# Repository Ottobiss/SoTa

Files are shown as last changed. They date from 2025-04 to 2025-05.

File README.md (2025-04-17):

<div align="center">
<p>
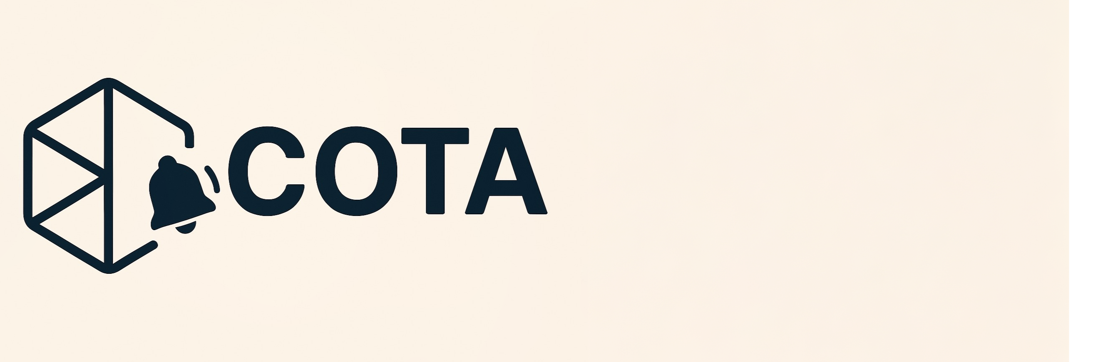
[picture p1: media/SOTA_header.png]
SOTA system banner

</p>




</div>

# 💊 Умная Таблетница «СОТА»

**Инженерно-программный проект**, направленный на создание универсальной системы контроля приёма различных лекарственных препаратов. Подразумевающий разработку умной таблетницы, сочетающей в себе простоту и эффективность использования. 

---
## 📷 Демонстрация

| Устройство | Интерфейс (...) |
|---|---|
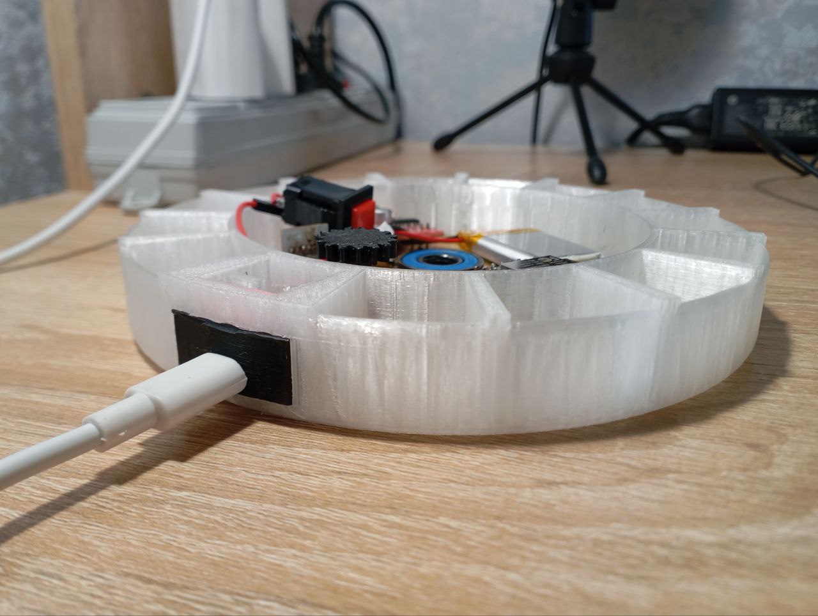
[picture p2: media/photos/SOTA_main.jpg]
SOTA demonstration
|  | ### |

---
## 📊 Что за «СОТА»?

Это **умная таблетница**, которая:
- 📱 Легко привязывается к специальному мобильному приложени.
- ✒️ Быстро и легко настраивается, учитывая при этом запросы пользователя.
- 🌐 Может подключаться к сети для более эффективной работы.
- 🔔 Напоминает о приёме лекарственных препаратов по расписанию.
- 💡 Подсвечивает и открывает нужный отсек в соответствии с конфигурацией.
- 📊 Хранит журнал приёмов и ведёт статистику.

---
## 🎯 Общие цели и принципы 
| Цель | Принцип |
|---|---|
| ⏰ Своевременный приём лекарств | Гибкая и удобная в настройке система, которая привязывает выдачу препарата к определённому времени. |
| 🔐 Исключение ошибок | Выдача препаратов производится автоматически без вмешательства человека. |
| 📲 Удалённый доступ | Возможность просмотра данных и настройки через приложение. |
| 🛠 Компактность конструкции | Умную таблетницу можно спокойно переносить в небольших сумках, рюкзаках и т.д. |
---
## 📦 Структура репозитория

```text
SoTa/
├── hardware/           ← Аппаратная часть: схемы, 3D-модели, прошивка
│   ├── schematics/     ─ Электросхемы, подключения
│   ├── 3d_models/      ─ Корпус таблетницы (STL/M3D/A3D)
│   └── firmware/       ─ Код для микроконтроллера (ESP32)

├── software/           ← Программная часть: веб-интерфейс, сервер, логика
│   ├── backend/        ─ Серверное API, алгоритмы на Python
│   └── app/    ─ автономное приложение

├── docs/               ← Документация, презентация, инструкции
├── media/              ← Фото, мокапы, скриншоты, демонстрации, лого и прочее
└── README.md           ← Вы здесь :)
```

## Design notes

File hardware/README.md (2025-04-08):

# 💡 Проектирование

Основной особенностью умной таблетницы **«СОТА»** является её небольшой размер, позволяющий носить её с собой в течение дня или держать рядом на небольшом столике. Именно поэтому при проектировании устройства особое внимание уделялось **балансу** между **вместимостью и компактностью**. 

---
## 🔧 Модель корпуса

Основной конструкционной идеей является механизм **револьверного типа**. Крашка таблетницы может поворачиваться на **заданную ячейку**, совершая выдачу **препаратов**, находящихся в этой ячейке.

| Ячейки | Крышка | Зарядный бокс |
|---|---|---|
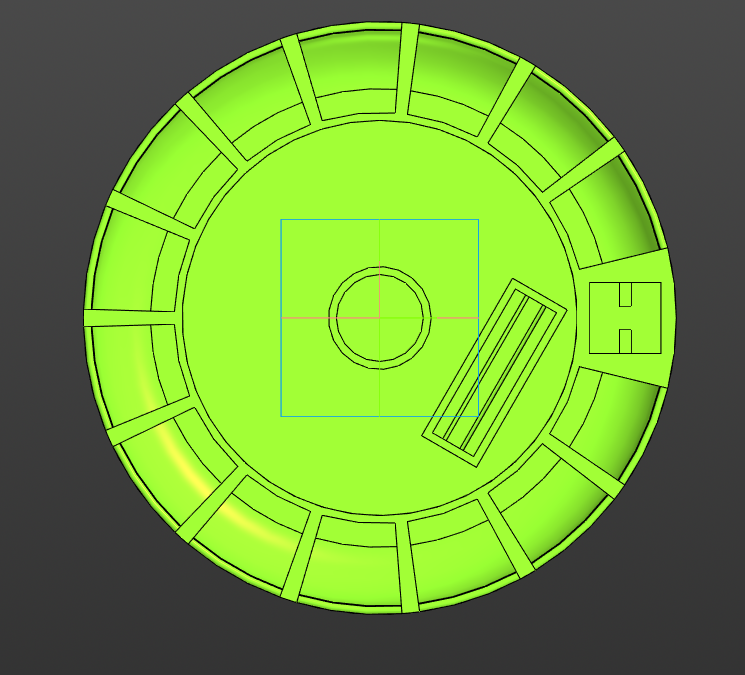
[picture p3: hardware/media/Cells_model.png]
Cells of SOTA
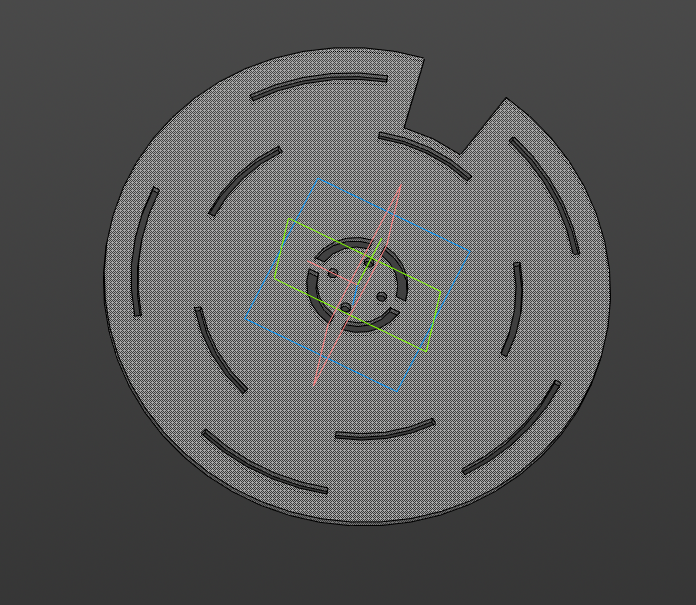
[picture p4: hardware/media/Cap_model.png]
Cap of SOTA
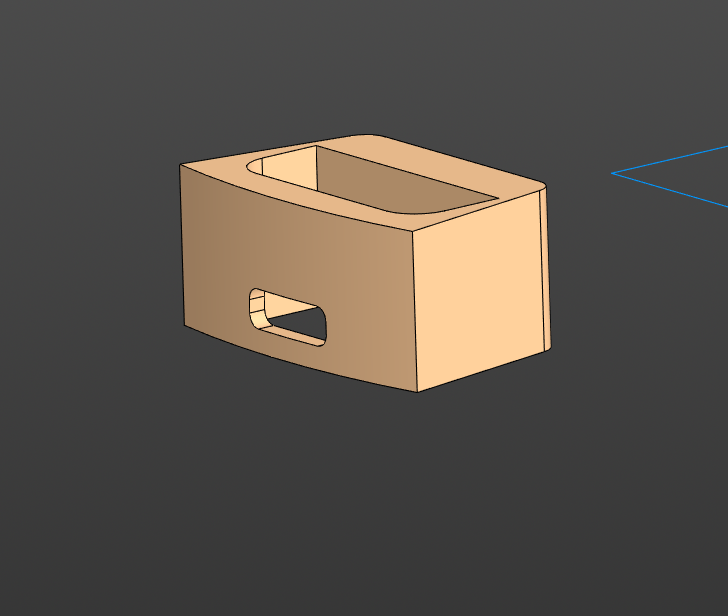
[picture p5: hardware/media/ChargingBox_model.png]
Charging box of SOTA
|  |  |  |
| Всего корпус таблетницы содержит **15 ячеек**, одна изкоторых является заглушкой. Размещение препаратов в ячейках может быть произвольным. | Крышка предназначена для выдачи препаратов в соответствии с **расписанием**, настроенным ранее в приложении, так, крышка проворачивается на нужную ячейку. | Зарядный бокс выполняет скорее **демонстративную функцию**. За ним находится зарядная плата с разъёмом **Type-C**, позволяющим программировать и заряжать умную таблетницу. |
---
## ⚡ Электроника

Решение делать **печатную плату** было принято не сразу. Сначала рассматривались варианты с производством платы по технологии **ЛУТ-а**, но она к сожалению не обладала достаточной точностью. Переносить дорожки с бумаги на **текстолит** было досточно проблематичным, даже при условии толщины дорожки в **1 мм**.
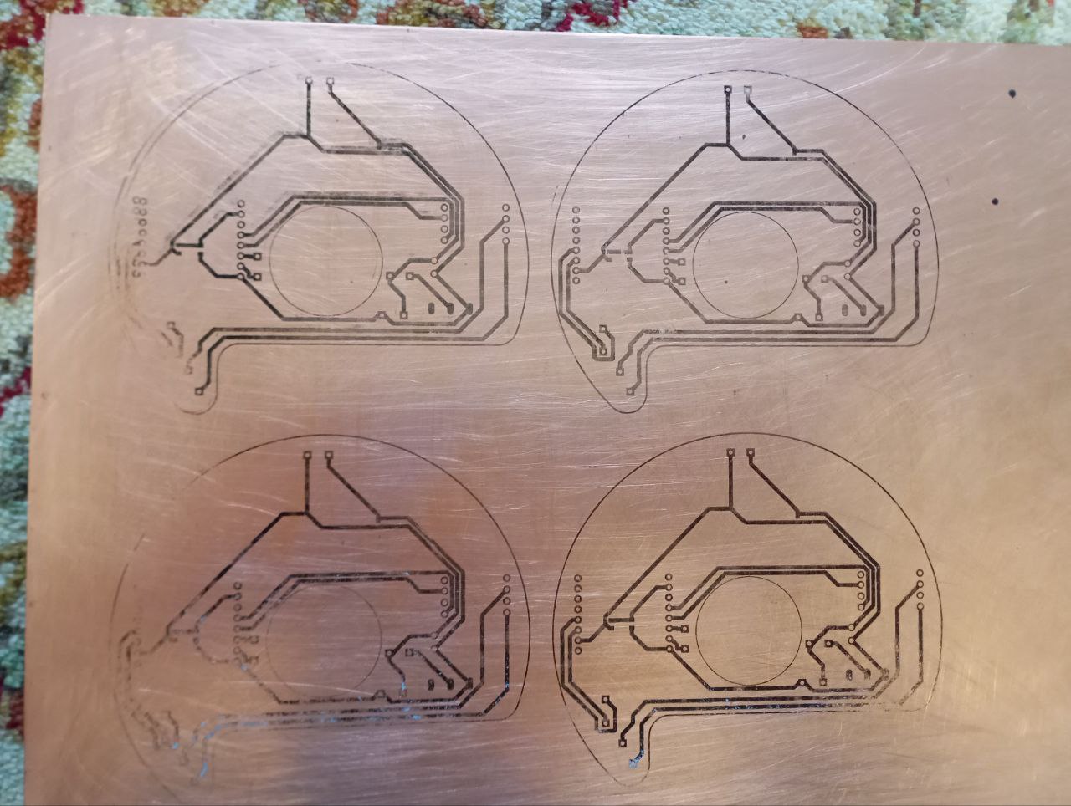
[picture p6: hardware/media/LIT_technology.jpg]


<p align="center"><i>Собственнл лист текстолита с несколькими платами. Да, из-за особенностей технологии некоторые дорожки перенеслись плохо и их пришлось дорисовывать.</i></p>

Была создана печатная плата. Она уже позволяла разместить больше компонет. Также ширина дорожек питания сократилась до **0.7 мм**, а ширина других до **0.3 мм**.

| Печатная плата 2D | Принципиальная схема |
|---|---|
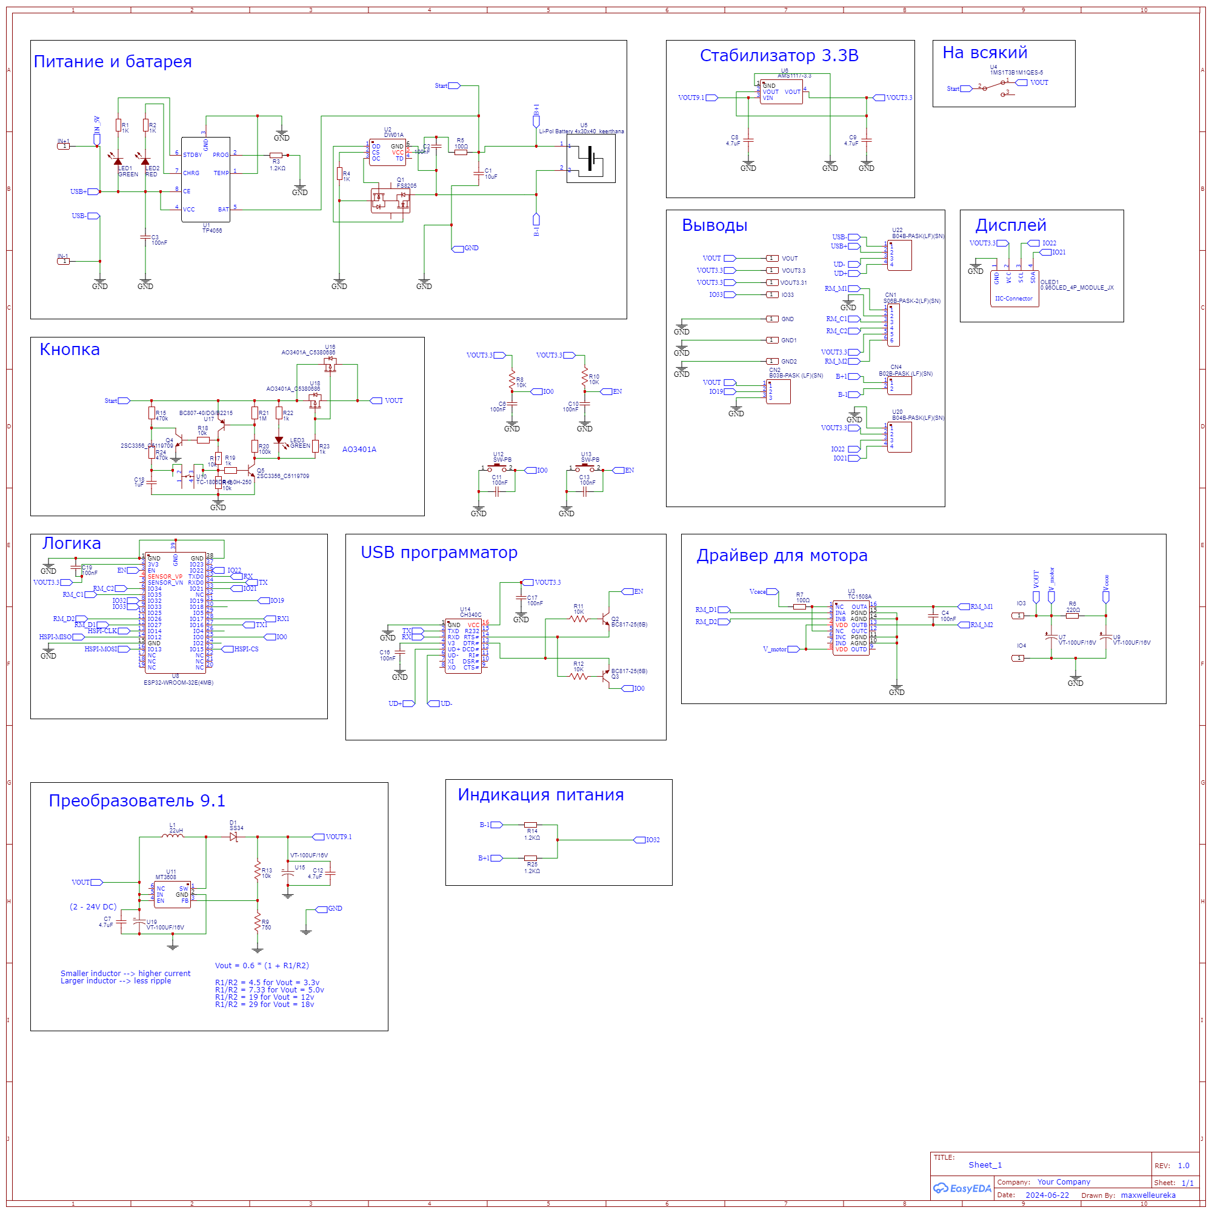
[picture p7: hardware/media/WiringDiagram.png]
Wiring diagram of SOTA
| <p align="center">Printing board of SOTA</p> |  |

## ▶️ Электроника в общем

```text
          +----------------------+
          |  Аккумулятор Li-Pol  |               #Питание поступает от аккумулятора 3.7 V и преобразуется в 9 V.
          +----------------------+               #Далее 9 V через стабилизатор понижаются до 3.3 V и проходят дальше.
                    |                            #От стабилизатора питаются ESP32, мотор с энкодером и LED-лента.
                  3.7 V                          #Управление всеми компонентами осуществляется с микроконтроллера.
                    ↓
          +----------------------+
          |  Преобразователь 9 V |
          +----------------------+
                    |                         
                   9 V                        +----------------------+
                    ↓                    ―― → |  LED лента           | ← ―
          +----------------------+      |     +----------------------+    |
          |                      |      |     +----------------------+    |
          |  Стабилизатор 3.3 V  | ―― 3.3 V → |  Мотор с энкодером   |    |
          |                      |            +----------------------+    |
          +----------------------+                              ↑         |
                    |                                           |         |
                   3.3 V                                        | ―― ―― ――
                    ↓                                           |
          +----------------------+                              |
          |  ESP32-WROOM         | ―― управляющее воздействие ――
          +----------------------+
```

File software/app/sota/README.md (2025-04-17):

# sota

A new Flutter project.

## Getting Started

This project is a starting point for a Flutter application.

A few resources to get you started if this is your first Flutter project:

- [Lab: Write your first Flutter app](https://docs.flutter.dev/get-started/codelab)
- [Cookbook: Useful Flutter samples](https://docs.flutter.dev/cookbook)

For help getting started with Flutter development, view the
[online documentation](https://docs.flutter.dev/), which offers tutorials,
samples, guidance on mobile development, and a full API reference.

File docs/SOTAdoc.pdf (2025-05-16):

Всероссийская олимпиада школьников по профилю «Технология»

«Робототехника»

Пояснительная записка к проекту

«СОТА»

Юдин Сергей Леонидович, 11 класс

Направляющая организация:

СОШИ «Лицей имени Н.И. Лобачевского» (далее - Лицей) – структурное

подразделение федерального государственного автономного

образовательного учреждения высшего образования «Казанский

(Приволжский) федеральный университет» (КФУ).

Научный руководитель:

Поликарпов Денис

Анатольевич

МАОУ СОШИ «СОлНЦЕ»

Казань 2025

Всероссийская олимпиада школьников по профилю «Технология»

«Робототехника»

Пояснительная записка к проекту

«СОТА»

Направляющая организация:

Научный руководитель:

Казань 2025

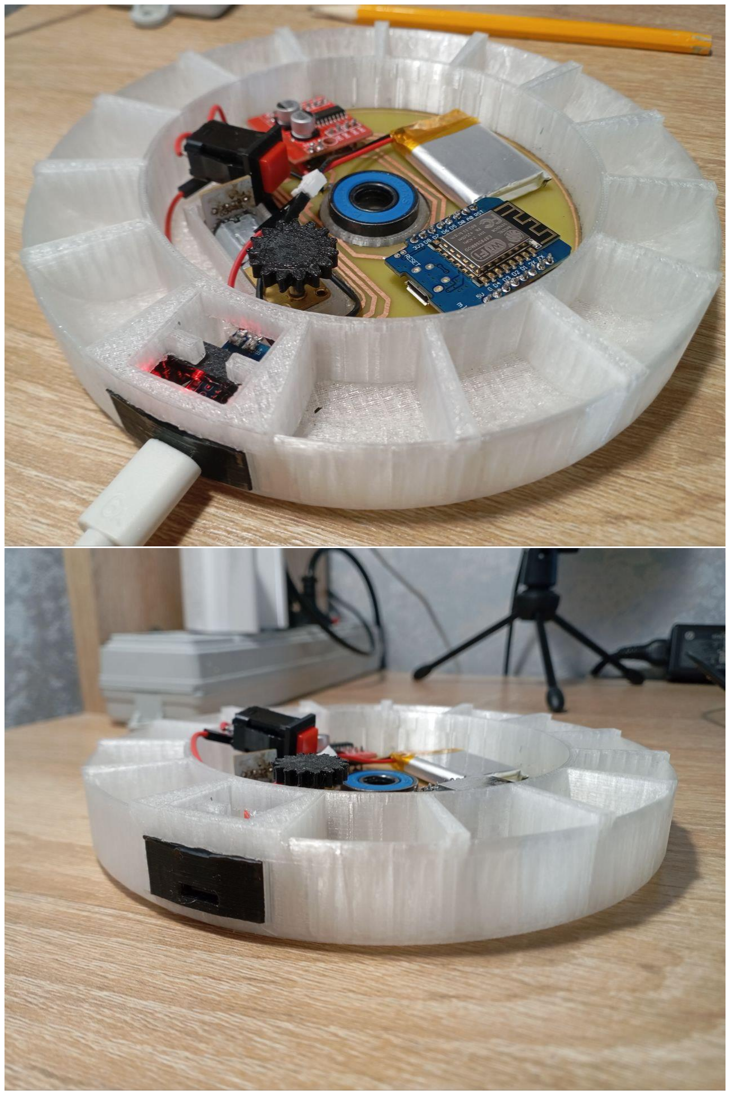
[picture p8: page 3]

ОГЛАВЛЕНИЕ

КРАТКОЕ ОПИСАНИЕ ПРОЕКТА И ВВЕДЕНИЕ «СОТА» — инновационное решение, которое позволит удобно и

эффективно контролировать прием лекарственных препаратов. Система

СОТА способна напоминать о приёме лекарственных препаратов, учитывая

количество препаратов и время приёма. Также система включает специальную

загрузочную станцию, на которой таблетница может пополнить свой запас

препаратов. Работу системы можно легко настроить с помощью интуитивно

понятного web-сервиса(приложения/Telegram-бота), который также позволит

следить за количеством препаратов в устройстве и оповещать о возможных

пропусках в их приёме, а также настраивать работу загрузочной станции.

Настройку можно проводить как удалённо, так и в непосредственной близости

к умной станции. Главная особенность состоит в способности системы

работать полностью автоматически. Именно это делает систему СОТА

уникальной для рынка подобных устройств в России и других странах мира.

Система особенно удобна для использования пожилыми людьми. В

данном случае их родственник или соц. работник может настроить СОТА под

запросы пожилого человека.

ПРОБЛЕМА И АКТУАЛЬНОСТЬ
В современном мире у людей часто возникают различные проблемы со

здоровьем, которые позже могут стать хроническими. Согласно данным

Всемирной организации здравоохранения (ВОЗ), хронические заболевания

ежегодно становятся причиной 74% всех смертей в мире, а их ранняя

манифестация среди населения встречается всё чаще. Также было отмечено

увеличение процента людей, принимающих те или иные лекарственные

препараты.

Все вышеуказанные факты подтверждаются проведенным мною

опросом (см. Приложение А), представленным на рисунке 1, где 65%

участников ответило «Иногда», отвечая на вопрос «Забываете ли вы

принимать свои лекарственные препараты?», 13% ответило «Часто» и 4% -

«Всегда».

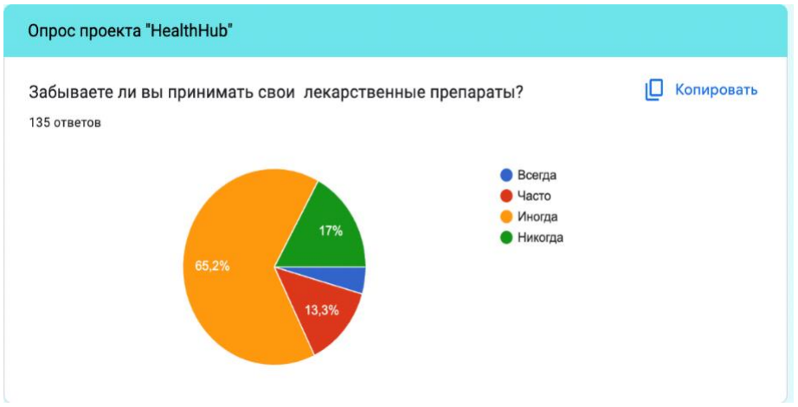
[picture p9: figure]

Рисунок 1 – диаграмма частоты пропускав лечения

Повышенная нагрузка на человека в течение дня способствует

пропускам в приёме лекарственных препаратов. После тяжёлого рабочего дня

не каждый способен вспомнить о приёме нескольких таблеток. Конечно же, в

дальнейшем это может иметь негативные последствия.

В особенно сложном положении оказываются пожилые люди, для

которых | приём | лекарственных | препаратов | является | обязательным.

Возрастные изменения и ухудшение памяти могут сильно повлиять на

регулярность приёма препаратов, необходимых им для комфортной жизни,

что в действительности может привести к плачевным последствиям.

Кроме того, важным аспектом данной проблемы является недостаточная

осведомлённость людей о возможных последствиях нерегулярного приёма

лекарств. Многие пациенты недооценивают серьёзность пропусков, особенно

если не сразу ощущают негативные последствия. Однако в долгосрочной

перспективе это может привести к снижению эффективности лечения,

развитию осложнений и даже необходимости более агрессивной медицинской

терапии.

ЦЕЛЬ И ЗАДАЧИ
Главная цель проекта — это решить проблему контроля режима приёма

лекарственных препаратов людьми, которые имеют заболевания различной

степени тяжести, требующие регулярного лечения и строгого режима приёма

препаратов.

Главная задача проекта — создать систему, имеющую удобную и

гибкую настройку, позволяющую контролировать приём лекарственных

препаратов и следить за режимом их принятия, как лично, так и через другие

лица (врачи, родственники, соц. работники), заинтересованные в соблюдении

режима приёма лекарственных препаратов.

В рамках проекта я выделил несколько подзадач, подразумевающих

разработку технического решения вышеописанной проблемы:

- Разработка компактного и эргономичного корпуса, учитывающего

удобство хранения и переноски.

- Разработка механизма выдачи препаратов с точной фиксацией для

исключения случайного открытия таблетницы.

- Разработка управляющего модуля таблетницы с учётом её размеров.
- Разработка корпуса и загрузочной станции.
- Проработка и реализация загрузочного механизма.
- Реализация системы связи между таблетницей и загрузочной станцией.
- Разработка удобного и специализированного web-сервиса для настройки

и управления умной таблетницей.

- Разработка системы связи между таблетницей и web-сервисом,
позволяющей | подключаться | к | персональной | таблетнице | в

непосредственной близости к ней и в дальнейшем управлять ей уже на

расстоянии.

ИССЛЕДОВАНИЕ
Для более чёткого понимания решаемой проблемы я также решил

провести собственное исследование и опросил более 140 респондентов.

Результаты опроса (см. Приложение А) полностью подтвердили как мои

догадки, так и данные из интернета.

В опросе были задействованы люди из разных возрастных групп (от 14

до 70 лет). Преобладающая часть опрошенных – девушки и женщины, что

составляют 67% от общей части опрошенных. Ниже приведена статистика,

отражающая общие тенденции проблематики проекта:

- Значительная часть опрошенных, составляющая 48% от общего числа

респондентов, имеет различные хронические заболевания.

- По частоте заболеваемости большая часть ответила, что болеют

несколько раз в год или реже. Около 15% респондентов болеют по

несколько раз в полгода.

- Более 77% респондентов вынуждены регулярно принимать различные

лекарственные препараты.

- Согласно данным опроса, значительная часть респондентов часто или

иногда забывает принимать лекарственные препараты.

- В среднем люди на постоянной основе принимают 3 различных вида

лекарственных препаратов. Более 25% респондентов принимают 4 и

более видов лекарств.

- Более 60% опрошенных принимают лекарственные препараты по

несколько раз в день.

Проведённый опрос подтверждает необходимость создания решения,

позволяющего удобно контролировать приём препаратов. Действительно,

люди вынуждены принимать достаточно большое количество препаратов, но

к сожалению они не всегда вспоминают про это в течение дня, несмотря на

свои заболевания, которые приносят им дискомфорт.

АНАЛОГИ, ПРЕДСТАВЛЕННЫЕ НА РЫНКЕ На данный момент прямых аналогов системы в России нет. Но есть

близкие по идее проекты (см. Приложение Б) в различных странах мира.

Например:

- VODESON Pill Organizer (https://www.amazon.com/VODESON-Organizer-Medicine-Dispenser-Supplements/dp/B09TB342HH) [9]:
- Страна разработчик – Китай.

Smart Medicine Box предназначен для пожилых, забывчивых людей и

некоторых людей, которым необходимо принимать лекарства,

витамины и добавки в течение длительного времени.

- CYCO и Pillgo Smart Pillbox (https://www.qualife.co/cyco) [2] [8]:
- Страна разработчик – Китай.

CYCO и Pillgo предлагают комплексное решение, основанное на данных

предоставления таблеток в сочетании с мобильными приложением.

Решение включает в себя заранее запланированные планы приема

лекарств, напоминания, функцию удаленного мониторинга для лиц,

осуществляющих уход, и всесторонние записи о приеме доз для

наблюдения за привычками пользователей для подробного анализа.

- IoT Smart Pillbox (https://tbdigitaladherence.org/technologies/smart-pill-box/) [3]:
- Международная разработка.

IoT Smart Pillbox – контейнер для лекарств, имеющий датчик с питанием

от батареи и мобильное подключение для передачи данных. Умная

таблетница автоматически регистрирует прием лекарств пациентом

каждый раз, когда пациент открывает контейнер, чтобы принять

лекарство. После этого таблетница отправляет сигнал о принятом

препарате.

- KIN Smart Pill Dispenser (https://www.kinhealthcare.co/) [4]:
- Страна разработчик – Китай.

KIN включает в себя автоматический дозатор таблеток The Kindo,

который выдает напоминания и может автоматически выдавать нужную

дозу в нужное время одним нажатием кнопки без предварительной сортировки. Он может соединяться с онлайн-приложением KIN (веб-

или мобильным) по беспроводной сети для удаленного мониторинга и

управления лекарствами и добавками в любое время и в любом месте.

- Memo Box Smart Pillbox (https://pillbox.tinylogics.com/) [5]:
- Страна разработчик – США.

Memo представляет собой компактную таблетницу, предназначенную

для использования вне дома. Memo способна автоматически напоминать

о приёме лекарственных препаратов и отмечать моменты, когда человек

пропустил приём таблеток, отображая их в мобильном приложении.

- Smart Bluetooth Pill Dispenser (https://aliexpress.ru/item/1005007336672163.html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) [6]:
- Страна разработчик – Китай.

Данный аппарат крайне схож с концепцией таблетницы «СОТА».

Устройство имеет револьверную систему, которая поворачивает

необходимую ячейку таблетницы к отверстию для выдачи. Эта

таблетница не имеет портативного варианта и предназначена для

размещения на вертикальных поверхностях (стены и т.д).

Большая часть умных таблетниц, представленных выше, предназначены для

использования вне дома, обладают относительно небольшим функционалом и

вместимостью. | Более | подробная | характеристика | каждого | продукта

представлены в таблице 1.

| | | | | Таблица 1

Характеристика существующих технических решений

Характеристика | Ст-сть | Функционал | Портативность | Страна
VODESON Pill Organizer | 29.99 $ | Напоминание, дисплей дозировки, работа от батареи | Малый размер. Существует только | Китай

CYCO и Pillgo Smart Pillbox | 58 $ | Напоминание, функция дозатора, ведение дневника | Малый размер. Существует только | Китай
IoT Smart Pillbox | 53.75 $ | Визуальное напоминание, энергоёмкость, | Большой размер. Существует только | Международн ая разработка
KIN Smart Pill Dispenser | ? $ | Напоминание, функция дозатора, ведение дневника | Существует две версии: портативная и | Китай
Memo Box Smart Pillbox | 89.90 $ | Оповещение визуально и через приложение, | Малый размер. Существует только | США
Smart Bluetooth Pill Dispenser | 90 $ | Звуковое оповещение, ручная настройка, | Большой размер, имеет только стационарную | Китай

Отдельно стоит отметить, что данные устройства не работают как

полноценная система для контроля над приёмом лекарственных препаратов.

Они имеют отдельные функции, но при этом не предлагают комплексного

подхода. Искулючением может послужить только устройство KIN Smart Pill

Dispenser, что имеет достаточно большую загрузочную станцию таблеток

(таблетницу), способной вмещать и хранить достаточное количество

препаратов.

ЦЕЛЕВАЯ АУДИТОРИЯ

Проведя анализ результатов опроса, представленного на рисунке 2, я

пришёл к выводу, что проблема пропуска приёма таблеток актуальна среди

всех групп возрастов. Так я выделили две группы особого приоритета:

- Люди 45-70 лет, для которых наиболее важен систематический приём

препаратов.

- Медицинские организации (клиники, больницы, поликлиники) с

большой нагрузкой на мед. персонал, где проходят реабилитацию люди

с заболеваниями, требующими регулярного приёма различных

лекарственных препаратов.

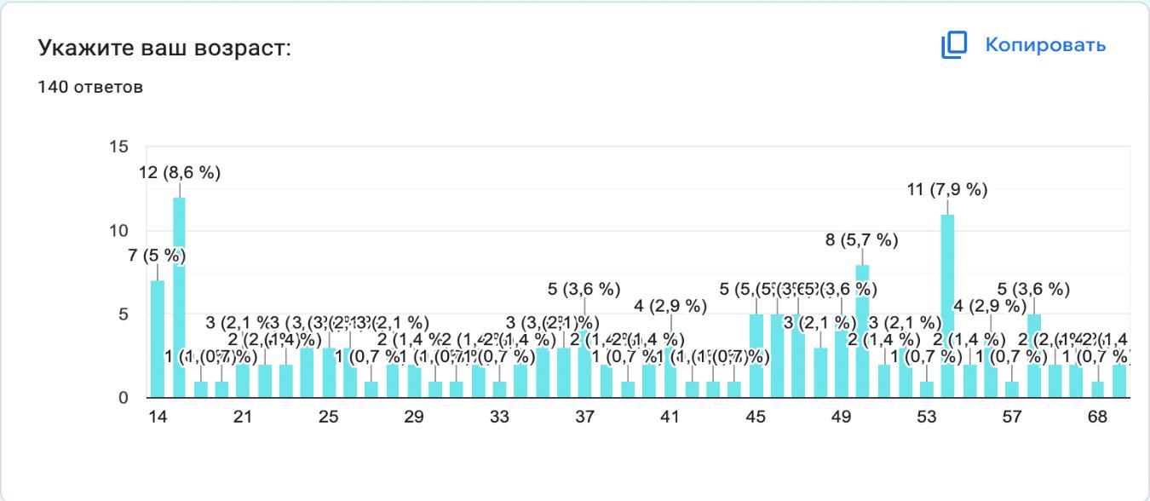
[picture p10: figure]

Рисунок 2 – диаграмма распределения аудитории по возрасту

В целом результаты опроса отражают действительную картину. Люди обычно

принимают какие-либо лекарственные препараты в период взросления для

поддержания гормонального фонда, иммунитета и т.д, то есть начиная с 14 и

до 16. А также среднее количество людей, принимающих различные

препараты увеличивается с возрастом. Важно отметить, данное распределение

по возрасту было реализовано только для той группы людей, что вынуждена

была регулярно принимать один или более препаратов.

КОНЦЕПЦИЯ И СХЕМА РАБОТЫ

«СОТА» — система, предназначенная для эффективного и удобного

контроля над приёмом лекарственных препаратов с учётом дозировок,

времени приёма и т.д. Система состоит из двух устройств: умной портативной

таблетницы и загрузочной станции. Оба устройства являются полностью

автономными, но вместе они позволяют выполнять поставленную задачу

эффективнее. Далее мы рассмотрим схему работы, обращаясь при этом к

пользовательскому | опыту | (см. | Приложение | Г) | и | сопроводим

функциональными заметками.

Саму же иерархию системы можно разбить на два блока: физические

устройства (таблетница, загрузочная станция) и web-сервис, предназначенный

для настройки и управления устройствами.

- Умная таблетница является станцией для хранения и выдачи таблеток.

Внутренняя часть таблетницы разделена на 15 отсеков, один из которых

играет роль заглушки. В каждую ячейку загружаются необходимые

человеку препараты. На данный момент их загрузка происходит

вручную, но дальнейшее развитие проекта подразумевает создание

специальной станции загрузки. Далее в соответствии с расписанием

приёма препаратов таблетница оповещает человека световым и

звуковым (в дальнейшем) сигналом о том, что нужно принять таблетки,

открывает нужную ячейку поворотом крышки с вырезом и ждёт, пока

человек заберёт препараты, после этого крышка встаёт в положение

заглушки.

- Загрузочная станция представляет собой устройство размером с

похожее по размерам и форме на небольшой кофе-аппарат. В верхней

части станции находятся запасы лекарственных препаратов, которые

должен принимать человек, а в нижней части специальная платформа,

которая позиционирует ячеек таблетницы относительно выдающего

таблетки сопла. При помещении портативной таблетницы в станцию,

загрузка начнётся автоматически в соответствии с расписанием и дозировками, которые пользователь указал ранее. При этом станция

может загружать разные препараты в одну ячейку, то есть, если в

расписании в одной ячейке таблетницы должно лежать несколько

различных препаратов, станция сначала загрузит по указанным ячейкам

один тип препарата, а потом другой тип, встречающийся в этих же

ячейках.

- Web-сервис предназначенный для гибкой настройки расписания приёма

препаратов и ведения статистики, а также для настройки работы умной

станции, если таковая требуется. Так, с помощью мобильного

приложения, родственник или мед. Работник, либо же сам человек

может настроить расписание, количество принимаемых препаратов и

препараты для выдачи в загрузочной станции. Также он сможет следить

за тем, соблюдает ли человек расписание, и принимает ли он

определённые препараты в нужное время. Настройка ячеек достаточно

гибкая. К каждой из них можно привязать конкретный тип препарата

или их группу. Также настройка может подразумевать особые ячейки, в

которых будут находится препараты, которые необходимо принимать

строго при определённых обстоятельствах (повышенное сердцебиение

или давление), данный функционал дополняется интеграцией в систему

других умных устройств. Соответствующие пункты настроек актуальны

и для загрузочной станции.

- Связка | таблетницы, | станции | загрузки | и | web-сервиса | будет

осуществляться через специальный код привязки, который будет

генерировать таблетница или загрузочная станция при включении и

сохранять в дальнейшем. Далее вы сможете настроить таблетницу и

станцию с помощью вышеуказанного сервиса, указав дни, время приёма

препаратов, их тип, распределение по ячейкам и т.д. После каждого

приёма лекарственных препаратов в приложении будет отображаться,

что таблетки были приняты. Затем эта информация будет включаться в

статистику приёма препаратов.

ГОСТ 60.0.0.4-2023
Робот — программируемый исполнительный механизм, обладающий

определенным уровнем автономности и предназначенный для выполнения

перемещения, манипулирования или позиционирования. Указанные действия

при этом робот осуществляет с целью выполнения задач по назначению.

Согласно данному определению умная таблетница и загрузочная

станция «СОТА» совершают задачу позиционирования: в первом случае своей

верхней крышки относительно ячеек самого бокса с препаратами в

зависимости | от | расписания | принимаемых | препаратов, | во | втором

позиционирование нижней платформы относительно загрузчика. Важно

отметить, что есть более ранний ГОСТ 2019 года, который требовал наличие

у робота хотя бы двух степеней свободны, но позднее данный пункт убрали,

сделав больший акцент на автономности устройства.

ПЛАН РЕАЛИЗАЦИИ И ТЕХНИЧЕСКОЕ ЗАЛАНИЕ

После разработки идеи был создан план для дальнейшей реализации

проекта, представленный в таблице 2.

Таблица 2

Процесс разработки проекта

№ п/п | Этап реализации проекта | Маркер выполнения
1. | Создание идеи, постановка целей и задач, поиск проблемы, поиск аналогов и исследование. | ✔
2. | Проработка концепции проекта и создание общих правил и целей дальнейшей разработки, а также проработка целевой аудитории проекта. | ✔
3. | Поиск необходимых для работы проекта компонентов, их тестирование и отбор. Разработка механизма, поворачивающего крышку таблетницы. | ✔
4. | Поиск составляющих, подходящих под функционал и размеры таблетницы (ESP32, ESP8266, небольшой мотор с энкодером постоянного тока, драйвер мотора). | ✔
5. | Проектирование 3D-модели прототипа корпуса умной таблетницы в “Компас”, который совмещал бы в себе компактность и вместимость. | ✔
6. | Разработка вместительной детали ячеек револьверного типа в среде «Компас». Создание и распределение пространства под электронику. | ✔
7 | Проработка креплений таблетницы для максимально простой и в то же время надёжной сборки. | ✔
8. | Разработка нескольких вариантов собственных плат, оптимизирующих размещение на ней основных компонент управляющей системы, в среде EasyEDA. | ✔

9. | Заказ печатной платы на производстве, а также самостоятельное изготовление платы посредством технологии ЛУТа. | ✔
10. | Разработка алгоритма и основных правил по которым будет работать умная таблетница. | ✔
11. | Пайка заказанной платы, проверка и внесение изменений. | ✔
12. | Заказ новой печатной платы с учётом прошлых недочётов. И повторная пайка ранее заказанной платы. | ✔
13. | Проектирование 3D-модели прототипа корпуса загрузочной станции. | ✔
14. | Разработка web-сервиса, представленного в виде приложения на Java. | ☐
15. | Разработка web-сервиса, представленного в виде Telegram бота. | ✔
16. | Сборка корпуса таблетницы и всех её основных компонент. Размещение и подключение электроники, проверка работоспособности механизма. | ✔
17. | Размещение электроники загрузочной станции, подбор компонент, реализация механизма загрузки. | ✔
18. | Сборка загрузочной станции и связка её работы с работой таблетницы. | ✔
19. | Внедрение в работу проекта фичей, упрощающих взаимодействие пользователя и таблетницы. | ☐

20. | Тестирование прототипа устройства и выявление недостатков. | ☐
21. | Внесение корректировок в конструкцию загрузочной станции. Проектировка загрузочного сопла, позволяющего выдавать таблетки по весу или количеству. | ✔
22. | Подведение итогов тестирование и доработка проекта. | ☐
23. | Внедрение функции подключения к таблетнице дополнительных устройств. | ✖
24. | Окончательное тестирование системы. Проработка возможностей удешевить производство системы. | ✖

Примечание к таблице 2

✔– реализовано

✖– не реализовано

☐ – в процессе реализации

ПОДБОР МАТЕРИАЛОВ И ПРОЕКТИРОВАНИЕ ПРОДУКТА

В процессе реализации проекта «СОТА» одной из главных моих целей

было создание удобного и компактного корпуса таблетницы, который

совмещал бы в себе при этом простоту и функциональность.

Поэтому при проектировании корпуса таблетницы и остальных её

компонент в программе «Компас» особое внимание уделялось обеспечению

большой вместимости и лёгкости таблетницы (см. Приложение В). Именно

поэтому был выбран круглый дизайн таблетницы, позволяющий сделать её

сравнительно небольшой по отношению к её вместимости. Впоследствии

было принято решение разработать корпус с 15-тью ячейками, одна из

которых являлась бы заглушкой, что позволило бы хранить в препараты на

ближайшие 2 недели при полной загрузке. Также в корпусе таблетницы

присутствует отверстие, предназначенное для зарядной платы, которая

вставляется отдельной деталью. Крышка таблетницы представляет из себя

диск из оргстекла. 3D модель представлена на рисунке 3.

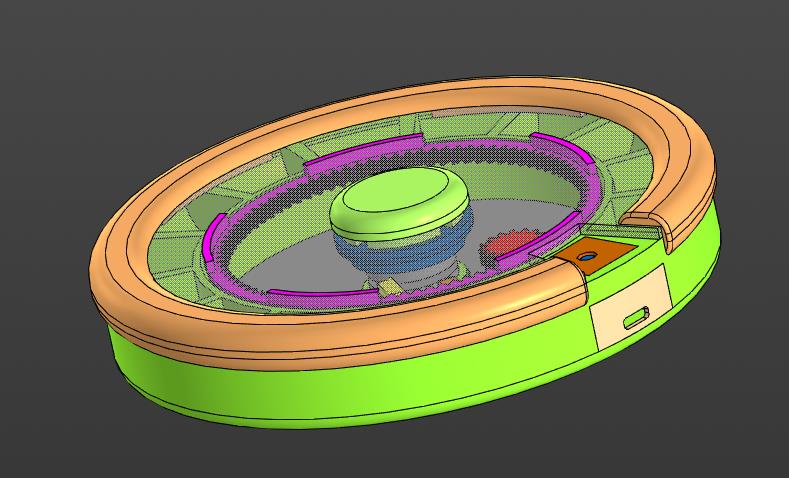
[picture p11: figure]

Рисунок 3 – корпус с ячейками таблетницы

Изготовление корпуса прототипа устройства будет проходить на 3D

принтере и лазерном ЧПУ станке в силу доступности данных технологий.

Большая часть деталей при этом будет распечатана на 3D принтере, что

позволит сделать достаточно прочный и эффективный корпус. При этом

подобных же правил придерживались при создании корпуса загрузочной

станции. Существует структурная схема обоих устройств (см. Приложение Д).

Электроника проекта представлена в обоих устройствах похожими

компонентами. | В | загрузочной | станции | мотором | с | энкодером,

преобразователем питания DC, платой ESP32 WEMOS, драйвером для

управления мотором и т.д. Далее разберём электронику таблетницы более

подробно.

Далее электроника и некоторые другие компоненты будут разделены на

два варианта прототипа проекта. На данный момент у умной табленицы СОТА

существует 2 версии, отличающиеся друг от друга управляющим модулем:

1. Управляющий модуль таблетницы представлен набором дискретных

компонент, расположенных на печатной плате, произведённой

посредством ЛУТа. В данном случае на плате находятся такие

компоненты как: WEMOS D1 mini на базе ESP8266, драйвер для мотора

LN298N и схема понижения напряжения. Плата и принципиальная

схема представлены на рисунке 4.

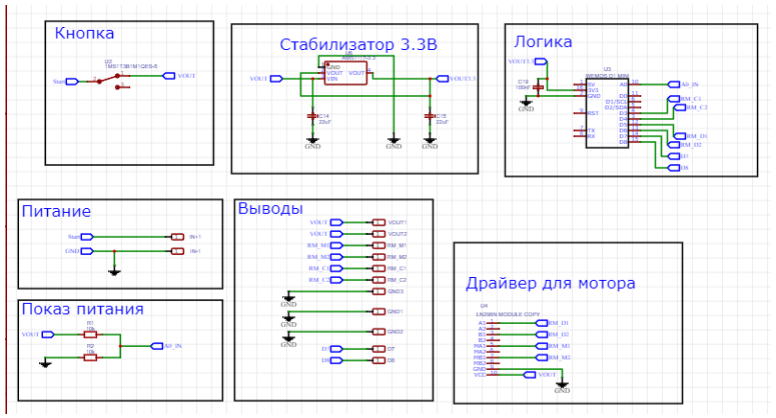
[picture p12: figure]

Рисунок 4 – плата на основе технологии ЛУТа

2. Управляющий модуль таблетницы представлен полноценной платой, заказанной на производстве. Подобный подход позволяет полностью

контролировать работу платы. Основным преимуществом данного

подхода является компактность конечной платы. В данном случае на

плате находятся такие компоненты как: ESP32, драйвер для мотора

TC1508A, схема понижения напряжения, входы USB и схема

программатора, позволяющая подключаться к таблетнице напрямую

через разъём Type-C, также на плате присутствует схема включения

таблетницы, посредством нажатия на тактовую кнопку в её корпусе.

Плата и принципиальная схема представлены на рисунке 5 и рисунке 6.

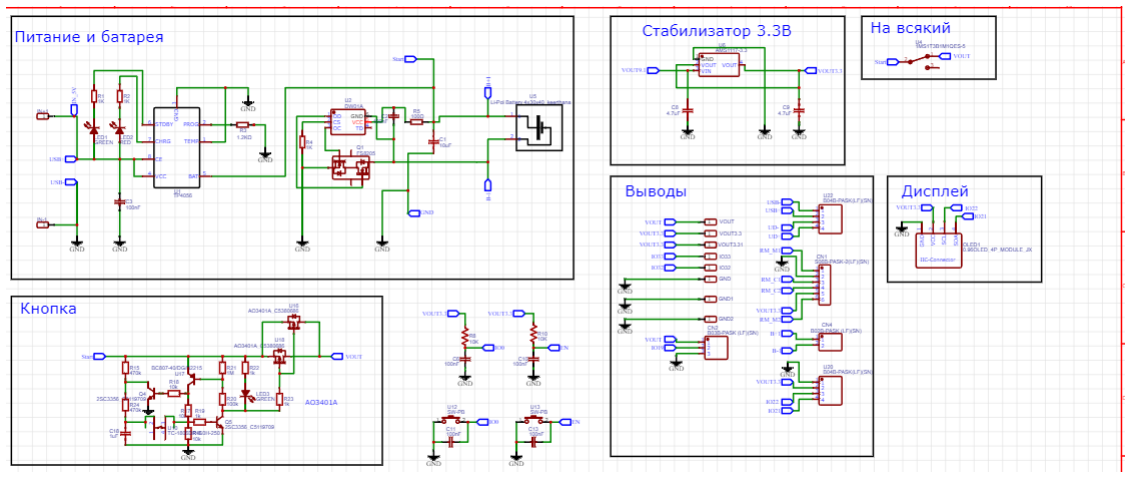
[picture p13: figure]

Рисунок 5 – часть заказной платы, отвечающая за питание.

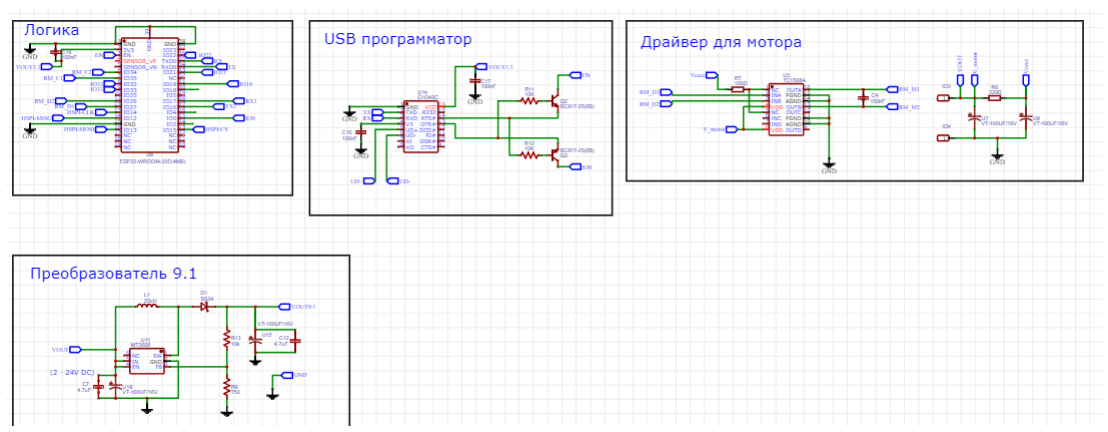
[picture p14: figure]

Рисунок 6 – часть заказной платы, отвечающая за логику.

В обоих случаях я решил использовать ESP, что позволит сильно

уменьшить размеры платы и увеличить вместимость таблетницы. Также

наличие ESP на плате позволит удалённо отправлять команды таблетнице и иметь доступ в сеть, а именно это необходимо для стабильной работы моего

проекта.

Также для создания упрощённого варианта платы, я создал собственный

прототип на основе лазерно-утюжной технологии (ЛУТа) с дискретными

компонентами. Здесь я столкнулся с рядом проблем, связанных с достаточно

трудоёмким процессом. При переносе тонера с глянцевой бумаги на текстолит

дорожки не всегда хорошо переносились, из-за чего их приходилось

докрашивать перманентным маркером. При этом я попробовал сделать как

вариант с двусторонней платой, так и с односторонней. В последнем случае

дорожки получались достаточно близко друг к другу, но при этом проблем с

переносом дорожек на второй слой платы не было, чего нельзя было

исключить в первом случае. Дальнейшие попытки выявили, что в плане

компактности и удобства размещения компонент первый вариант таблетницы

оказался более эффективным при решении поставленной задачи.

Также для реализации технического функционала таблетницы и

загрузочной станции был реализовывал алгоритм работы системы обмена

данными (см. Приложение З). В одной из версий использовался ТГ бот,

написанный с помощью библиотеки aiogram на Python. Фрагмент кода

представлен на рисунке 7.

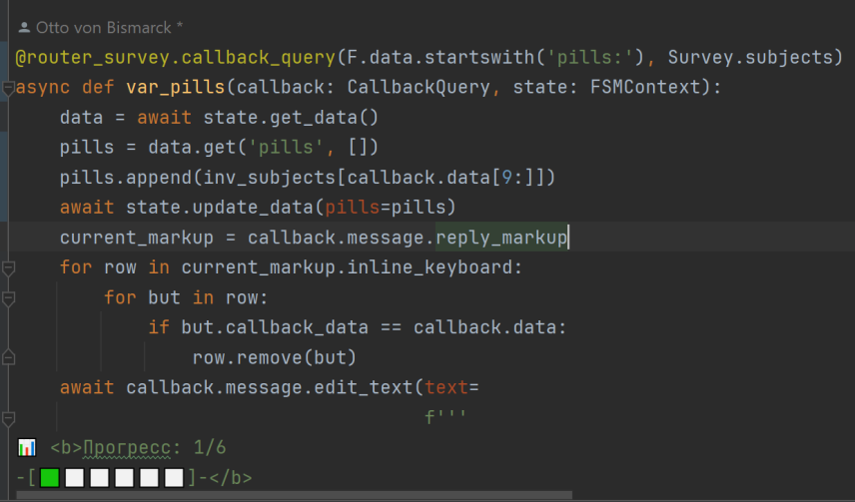
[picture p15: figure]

Рисунок 7 – фрагмент кода бота, функционал настройки таблетницы

Для добавления функций, упрощающих взаимодействие устройства и

пользователя, я использовал Arduino C, который позволял мне реализовать такой функционал, как подключение к WiFi через web-интерфейс и т.д. Также

был реализован функционал светодиодной ленты и т.д. Фрагмент кода

представлен на рисунке 8.

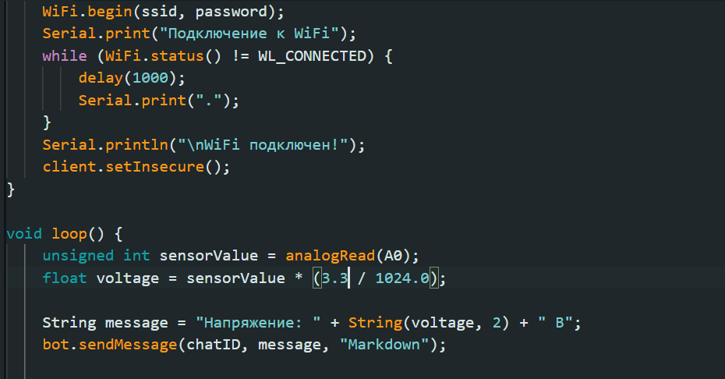
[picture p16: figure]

Рисунок 8 – фрагмент кода индикации заряда батареи

На данный момент (во второй версии) уже действует мобильное

приложение на языке Java в среде программирования Android Studio. Уже

реализован основной и достаточный функционал, связанный с хранением

данных и авторизацией, а также настройкой расписания. Мобильное

приложение является более предпочтительным на данный момент вариантом,

т.к позволяет взаимодействовать с пользователем на более высоком уровне.

Фрагмент кода представлен на рисунке 9.

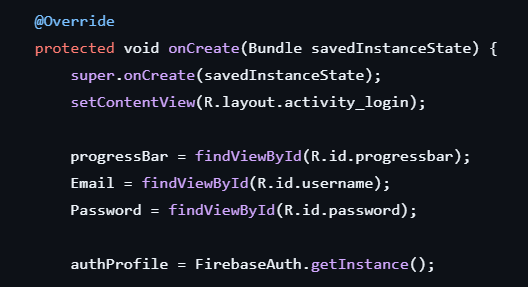
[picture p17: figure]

Рисунок 9 – фрагмент кода аутентификации в приложении

ЭКОНОМИЧЕСКОЕ ОБОСНОВАНИЕ И ПЕРСПЕКТИВЫ

Приведённые ниже расчёты были произведены для понимания общей

стоимости таблетницы. Загрузочная станция на данный момент в рассчёт не

берётся.

В процессе работы над проектом также выяснилось, что при заказе

печатных плат, производство 3 плат стоило всего 6 000 рублей. При этом

увеличение партии заказа способствовало уменьшению цены отдельно взятой

платы. Это может значить, что при увеличении партий себестоимость

производства одной платы будет уменьшаться и в перспективе будет стоить

около 1 500 рублей, что уменьшает себестоимость одной единицы продукта до

3 000 рублей, а конечную стоимость продукта до 8 312 рублей. Что ставит

умную таблетницу «СОТА» по цене на один уровень с умными станциями и

их вариациями из различных стран мира.

Ниже приведены таблицы расчёта стоимости конечного продукта.

Таблица 3

Общие затраты на производство и разработку проекта

Статья расходов | Стоимость
Аренда помещения и приобретение оборудования | 409 640 рублей
Затраты на труд и разовые затраты в течение года | 1 620 000 рублей
Затраты на производство предположительно 480 единиц товара в год. | 1 151 520 рублей
ИТОГО: | ≈ 3 181 160 рублей
На основе расчётов из таблицы 3 и количества производимого товара в

год себестоимость продукта равна 6 627 рублей, добавляя к этому наценку в

15%, получаем, что единица продукта стоит 7 621 рублей.

Данные числа дают оценку приблизительной стоимости единицы

продукта. В действительности эти расчёты могут немного отличаться. Более

подробно с расчётами и проектом в целом можно ознакомиться в

репозитории проекта на GitHub[20].

УНИКАЛЬНОСТЬ ПРОЕКТА

На данный момент проект является инновационным для внутреннего

рынка России. Также хотелось бы отметить, что в мире есть похожие проекты,

но все они уступают таблетнице СОТА по нескольким пунктам. Более

Подробная информация о сравнительной характеристике проекта СОТА с

другими похожими проектами находится в таблице 4.

Таблица 4

Сравнительная характеристика проекта СОТА и его аналогов

Характеристика Продукт | Вместимость | Ведение статистики лечения | Функция дозатора | Возможность гибкой настройки | Автоматическая выдача препаратов
СОТА | Большая | Есть | Есть | Есть | Есть
VODESON Pill Organizer | Маленькая | Отсутствует | Отсутствует | Отсутствует | Отсутствует
CYCO и Pillgo Smart Pillbox | Маленькая | Есть | Есть | Есть | Отсутствует
IoT Smart Pillbox | Большая | Отсутствует | Отсутствует | Отсутствует | Отсутствует
KIN Smart Pill Dispenser | Большая | Есть | Есть | Отсутствует | Есть
Memo Box Smart Pillbox | Маленькая | Отсутствует | Отсутствует | Отсутствует | Отсутствует

Проанализировав аналоги, представленные на рынке, мы выделили

несколько основных конкурентных преимуществ:

- Автоматическая выдача лекарственных препаратов. Наше решение, в

отличие от конкурентов, имеет преимущество в том, что выдача

таблеток происходит полностью автоматически.

- «Антивандальность» системы. Доступ к таблеткам предоставляется

только по расписанию, которое устанавливается доктором или

родственником. | Пенсионер | или | другой | человек | не | способен

самостоятельно получить к ним доступ, а значит принять излишки.

Таблетница высылает предупреждения на мобильное приложение, если

предпринимаются попытки вскрыть ее.

- Ведение статистики приёма препаратов. В мобильном приложение

можно посмотреть дни и часы, когда человек принял или не принял тот

или иной препарат.

- Гибкая настройка. Таблетницу можно легко и просто настроить с

помощью приложения, в котором можно указать количество

препаратов, дни и часы их принятия, наименование препаратов. В

дальнейшем эти данные нужны будут для ведения статистики.

- Групповое использование. Систему СОТА могут использовать

одновременно несколько человек. Для этого нужно просто перейти в

приложении в групповой режим и привязать к пользователям

препараты, которые они должны принимать.

ИТОГИ И РЕЗУЛЬТАТЫ

На данный момент готова пробная комплектация таблетницы и

реализован | базовый | функционал | с | несколькими | дополнительными

функциями. Достаточно сложной задачей было уместить такое большое

количество электроники и прочих компонентов в корпус таблетницы. Само

решение показало себя достаточно эффективным, что делает умную

таблетницу удобной для переноски в рюкзаках, сумках и достаточно больших

карманах. Сам корпус имеет размеры около 15 сантиметров в диаметре и 2

сантиметров в высоту. На данный момент в качестве web-сервиса выступает

ТГ бот и приложение на андроид, написанное на Java. Базовый функционал

включает в себя настройку расписания, таймеры, ведение статистики и т.д.

Также | внедряется | ИИ, | для | более | персонализированного | приёма

лекарственных препаратов. На данный момент таблетница использует

собственную плату, заказанную на производстве у «Резонита». С

продвижением проекта и его различными итерациями можно ознакомиться на

GitHub в моём репозитории[20]. Важно отметить, что проект имеет достаточно

много перспектив в развитии. Его действительно можно и нужно продвигать,

как настоящий продукт для людей с различными заболеваниями. Отдельно

хотелось бы выделить перспективу работы проекта в различных мед.

учреждениях. | Предполагается, | что | система | «СОТА» | будет | иметь

соответствующий товарный знак (см. Приложение Ж).

СПИСОК ЛИТЕРАТУРЫ

1. Хронические | заболевания | [Электронный | ресурс]: | платформа

Комерсантъ. – Режим доступа: https://www.kommersant.ru/doc/6745632.

2. CYCO [Электронный ресурс]: платформа Qualife. – Режим доступа:

https://www.qualife.co/cyco.

3. IoT Smart Pillbox [Электронный ресурс]: платформа TB DIGITAL
ADHERENCE. | – | Режим | доступа:

https://tbdigitaladherence.org/technologies/smart-pill-box/.

4. KIN Smart Pill Dispenser [Электронный ресурс]: платформа KIN. –

Режим доступа: https://www.kinhealthcare.co/.

5. Memo Box Smart Pillbox [Электронный ресурс]: платформа Tinylogics. –

Режим доступа: https://pillbox.tinylogics.com/.

6. Smart Bluetooth Pill Dispenser [Электронный ресурс]: платформа

AliExpress. – Режим доступа: https://clck.ru/3KAvBC.

7. PETG пруток BestFilament 1.75 мм, 1 кг, 1 л, красный, 1.75 мм

[Электронный ресурс]: платформа Яндекс Маркет. – Режим доступа:

https://clck.ru/3KAtg6.

8. Pillgo [Электронный ресурс]: платформа Qualife. – Режим доступа:

https://www.qualife.co/pillgo.

9. VODESON Weekly (7days) Travel Pill Organizer [Электронный ресурс]:
платформа | amazon. | – | | Режим | доступа:

https://www.amazon.com/VODESON-Organizer-Medicine-Dispenser-

Supplements/dp/B09TB342HH.

10.Выбор подходящего режима налогообложения [Электронный ресурс]:

официальный | информационный | ресурс | Федеральной | налоговой

службы. – Режим доступа: https://www.nalog.gov.ru/rn77/service/mp/.

11.Как составить бизнес-план [Электронный ресурс]: информационный

ресурс | ТИНЬКОФФ | ЖУРНАЛ. | – | Режим | доступа:

https://journal.tinkoff.ru/guide/business-plan/.

12.Макетная плата ESP32 1 шт., Wi-Fi + Bluetooth, сверхнизкое

энергопотребление, два ядра [Электронный ресурс]: платформа

AliExpress. | – | Режим | доступа:

https://aliexpress.ru/item/1005001636295529.html?sku_id=1200001691686

6581&spm=a2g2w.productlist.search_results.3.730a4aa6VQr4dc.

13.Работа программистом Java в Казани [Электронный ресурс]: платформа

hh.kz. – Режим доступа: https://kazan.hh.ru/vacancies/programmist_java.

14.Работа 3D-моделлером в Казани [Электронный ресурс]: платформа

hh.kz. – Режим доступа: https://kazan.hh.ru/vacancies/3d-modeller.

15.Стоимость разработки мобильного приложения [Электронный ресурс]:

информационный | ресурс | ИНОСТУДИО. | – | Режим | доступа:

https://inostudio.com/blog/articles-develop/stoimost-razrabotki-mobilnogo-

prilozheniya/.

16.Упорные | подшипники | [Электронный | ресурс]: | платформа
ВсеИнструменты.ру. | – | Режим | доступа:

https://kazan.vseinstrumenti.ru/category/upornye-podshipniki-171824/.

17.Аккумулятор литий-полимерный [Электронный ресурс]: платформа

chipdip.ru. – Режим доступа: https://www.chipdip.ru/product/lp502030.

18.ESP32-WROOM-32D | [4MB] | [Электронный | ресурс]: | платформа

chipdip.ru. – Режим доступа: https://www.chipdip.ru/product/esp32-wroom-

32d-4mb.

19.Двигатель | постоянного | тока | 1218-N20 | [Электронный | ресурс]:

платформа AliExpress. – Режим доступа: clck.ru/3KFGS6.

20.Репозиторий проекта SoTa [Электронный ресурс]: платформа GitHub. –

Режим доступа: https://github.com/Ottobiss/SoTa.

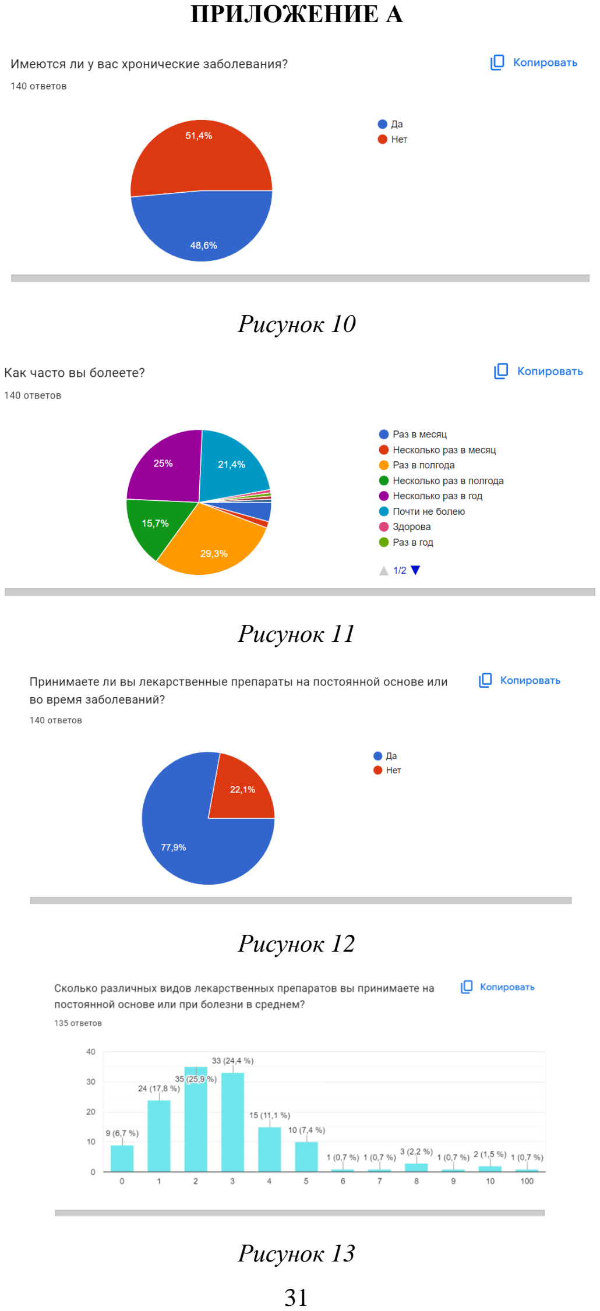
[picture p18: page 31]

ПРИЛОЖЕНИЕ А

Рисунок 10

Рисунок 11

Рисунок 12

Рисунок 13

ПРИЛОЖЕНИЕ Б

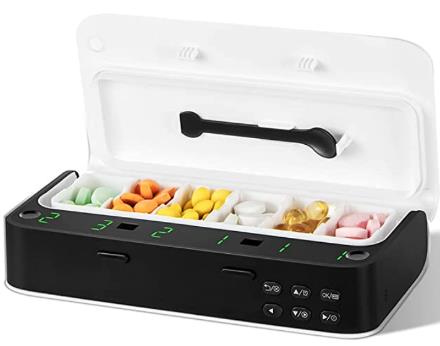
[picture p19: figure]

Рисунок 14

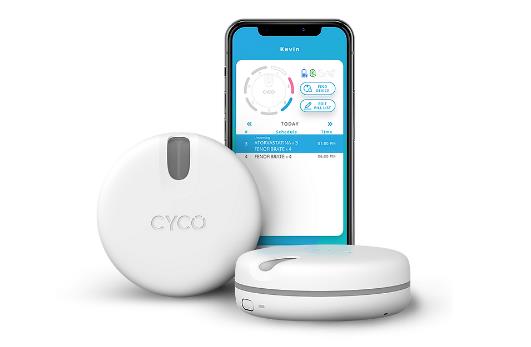
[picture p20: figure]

Рисунок 15

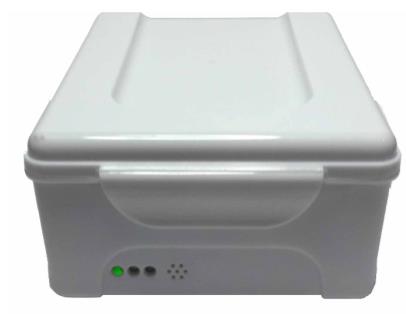
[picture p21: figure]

Рисунок 16

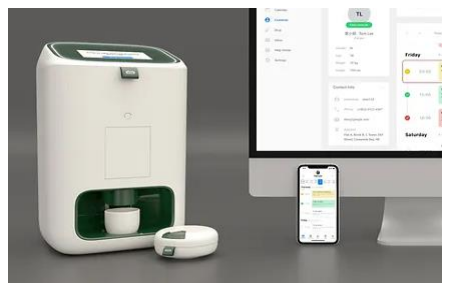
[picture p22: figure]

Рисунок 17

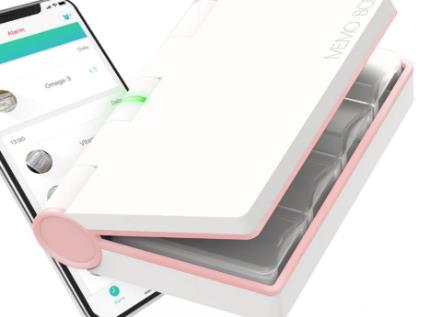
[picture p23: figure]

Рисунок 18

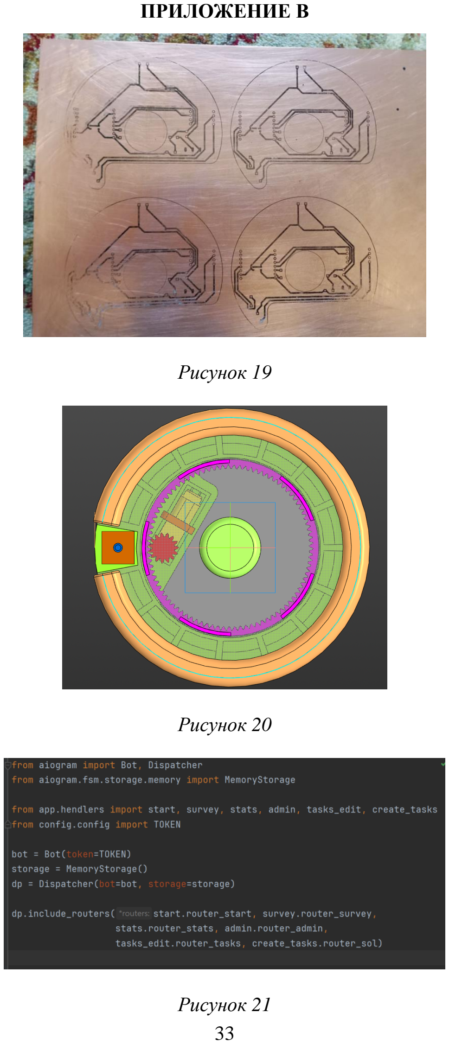
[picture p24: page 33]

ПРИЛОЖЕНИЕ В

Рисунок 19

Рисунок 20

Рисунок 21

ПРИЛОЖЕНИЕ Г

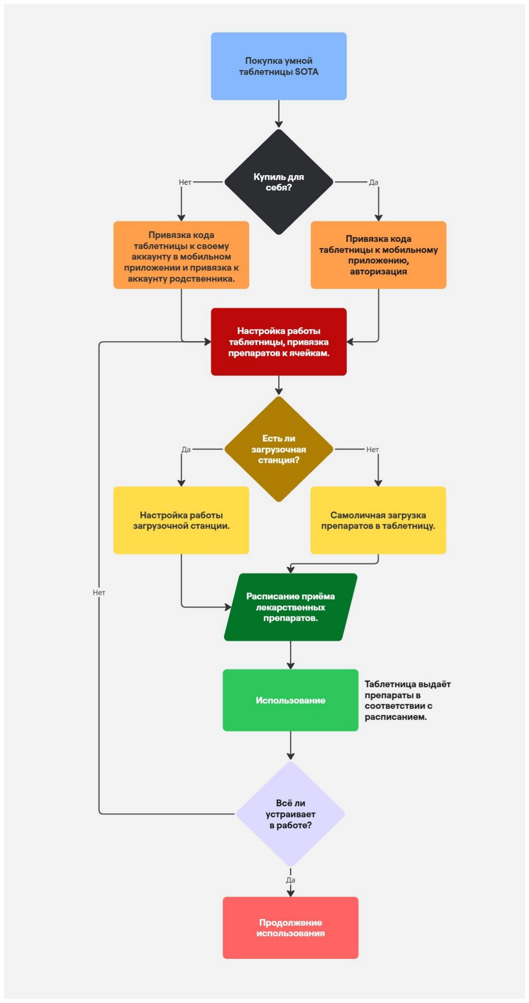
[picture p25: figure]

Рисунок 23

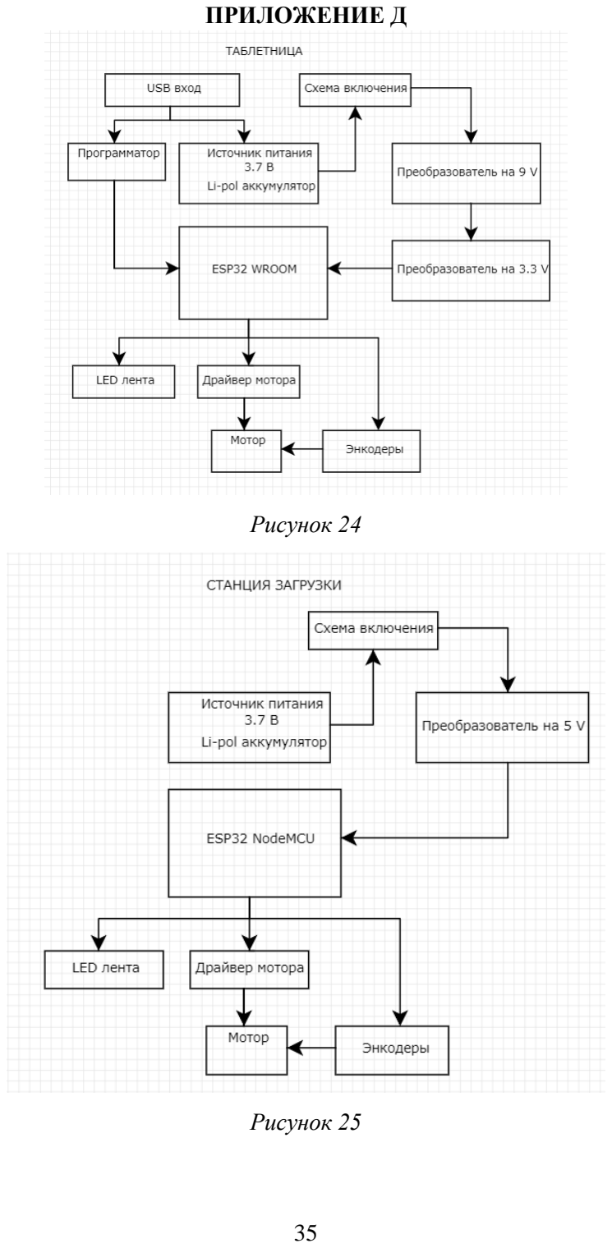
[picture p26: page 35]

ПРИЛОЖЕНИЕ Д

Рисунок 24

Рисунок 25

ПРИЛОЖЕНИЕ Ж


Рисунок 26

ПРИЛОЖЕНИЕ З


Рисунок 27

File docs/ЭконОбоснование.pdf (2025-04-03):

светодиодной ленты и т.д. Фрагмент кода представлен на рисунке 7.


Рисунок 7 – фрагмент кода индикации заряда батареи

На данный момент некоторые функции находятся в активной разработке и

задействованы лишь частично. Также вторая плата на данный момент ещё не пришла, но

заказ уже был отправлен и обработан на производстве, находящемся в Москве.

Экономическое обоснование и бизнес-план

Бизнес-план расписан по стандартам UNIDO [13], исключая разделы: описание

товара, продажи и маркетинг, резюме, гарантии и риски, приложения.

Проект СоТа действует в сфере материального производства, предоставляя готовый

продукт физическим или юридическим лицам.

Для серийного производства продукта из оборудования требуются 3D принтеры,

оборудование и инструменты для сборки продукта, верстак для сборки. Также требуется

использование расходных материалов, представленных в таблице 3. При серийном

производстве партиями примерно по 40 единиц товара в месяц требуется использование не

более 3-4 принтеров. Сборка продукта требует соответствующее рабочее пространство. Для этих целей необходим просторный верстак, занимающий около 3 м²
. Отталкиваясь от
размеров оборудования, мы предполагаем аренду помещения площадью 16 м²
. Само

предприятие (помещение, склад и т.д) может находиться в любом крупном городе

европейской части России.

Производство умных таблетниц СоТа требует нескольких видов технологий,

значительно упрощающих процесс производства и сборки конечного продукта:

- Печать корпуса таблетницы на 3D принтере.
- Резьба на лазерном станке деталей из акрила.

- Производство печатных плат.

Таблица 3

Комплектующие и их стоимость для сборки единицы товара

Компонент | Стоимость
NodeMcu ESP 32 | 195 рублей
Модуль заряда | 300 рублей
Сервомотор | 115 рублей
Два аккумулятора | 550 рублей
Подшипники | 200 рублей
Различные расходники (провода и т.д) | ≈ 300 рублей
Пластик | 440 рублей
Акрил, лист (594x420 мм) 4 мм | 1 682 рубля
Итого: | 3 782 рублей

Затраты на аренду помещения и приобретение оборудования были рассчитаны на

работу проекта в течение года. Более подробную информацию можно найти в таблице 4.

Таблица 4

Таблица затрат на аренду и приобретение оборудования для работы в течение года

Статья расходов | Стоимость
Аренда помещения | 195 840 рублей (16 320 руб/мес)
Оборудование для сборки | ≈ 11 300 рублей
Верстак | 82 500 рублей
3D Принтеры 4 штуки | 120 000 рублей
Итого: | 409 640 рублей

Для комплектации таблетницы необходим сборщик с инженерным образованием. На

данный момент средняя зарплата сборщика составляет 30 000 руб/мес. В рамках серийного

производства маленькими партиями достаточно одного сборщика.

Также для реализации проекта требуются «разовые» затраты на написание

алгоритма работы таблетницы и мобильного приложения.

С затратами на труд и «разовыми» затратами в течение одного года работы проекта

можно подробнее ознакомиться в таблице 5.

Таблица 5

Затраты на труд и «разовые» затраты в течение года

Статья расходов | Стоимость
Моделирование инженерного решения | 20 000 рублей
Разработка мобильного приложения | 1 000 000 рублей
Написание кода для работы таблетницы | 240 000 рублей
Оплата работы сборщика в течение года | 360 000 рублей (30 000 руб/мес)
Итого: | 1 620 000 рублей

Для формирования итоговой стоимости единицы продукта мы просуммировали все

затраты на производство за год с учётом количества производимого товара. Т.к один

принтер может полностью напечатать корпус таблетницы за два дня, то четыре принтера за

два дня напечатают детали уже для четырёх таблетниц. Т.к в месяце около 20 рабочих дней,

то за эти дни принтеры напечатают детали примерно для 40 единиц продукта. Из этого

следует, что в год будет выпускаться около 480 единиц продукта. Общие затраты на работу

проекта в течение года представлены в таблице 6.

Таблица 6

Общие затраты на работу проекта в течение года

Статья расходов | Общая стоимость
Разработка ПО и оплата труда | 1 620 000 рублей
Затраты на аренду и оборудование | 409 640 рублей
Затраты на производство 480 единиц продукта | 1 815 360 рублей
Итого: | 3 845 000 рублей

На основе расчётов из таблицы 6 и количества производимого товара в год

себестоимость продукта равна 8 010 рублей, добавляя к этому наценку в 15%, получаем, что единица продукта стоит 9 212 рублей.

Тогда при учёте, что весь производимый товар будет покупаться в течение года, то

выручка составит около 4 518 240 рублей, а прибыль без учёта налоговых вычетов около

589 840 рублей.

Для реализации стартапа в рамках небольшого производства наиболее подходящей

правовой формой будет ИП (Индивидуальный предприниматель) [19], а наиболее

подходящей при данных условиях системой налогообложения УСН (Упрощённая система

налогообложения) [23].

Экономические перспективы

Также мы выяснили при заказе печатных плат, что производство 3 плат стоило всего

6 000 рублей, это может значить, что при увеличении партий себестоимость производства

одной платы будет уменьшаться и в перспективе будет стоить около 1 500 рублей, что

уменьшает себестоимость одной единицы продукта до 3 000 рублей, а конечную стоимость

продукта до 8 312 рублей. Что ставит умную таблетницу СоТа по цене на один уровень с

умными станциями и их вариациями.

Уникальность проекта и конкурентные преимущества

На данный момент проект является инновационным для внутреннего рынка России.

Также хотелось бы отметить, что в мире есть похожие проекты, но все они уступают

таблетнице СоТа по нескольким пунктам. Более Подробная информация о сравнительной

характеристике проекта СоТа с другими похожими проектами находится в таблице 7.

Таблица 7

Сравнительная характеристика проекта СоТа и его аналогов

Характеристика Продукт | Вместимость | Ведение статистики лечения | Функция дозатора | Возможность гибкой настройки | Автоматическая выдача препаратов
СоТа | Большая | Есть | Есть | Есть | Есть
VODESON Pill Organizer | Маленькая | Отсутствует | Отсутствует | Отсутствует | Отсутствует
CYCO и Pillgo Smart Pillbox | Маленькая | Есть | Есть | Есть | Отсутствует
IoT Smart Pillbox | Большая | Отсутствует | Отсутствует | Отсутствует | Отсутствует

KIN Smart Pill Dispenser | Большая | Есть | Есть | Отсутствует | Есть
Memo Box Smart Pillbox | Маленькая | Отсутствует | Отсутствует | Отсутствует | Отсутствует

Проанализировав аналоги, представленные на рынке, мы выделили несколько

основных конкурентных преимуществ:

- Автоматическая выдача лекарственных препаратов. Наше решение, в отличие от

конкурентов, имеет преимущество в том, что выдача таблеток происходит

полностью автоматически.

- «Антивандальность» системы. Доступ к таблеткам предоставляется только по

расписанию, которое устанавливается доктором или родственником. Пенсионер или

другой человек не способен самостоятельно получить к ним доступ, а значит

принять | излишки. | Таблетница | высылает | предупреждения | на | мобильное

приложение, если предпринимаются попытки вскрыть ее.

- Ведение статистики приёма препаратов. В мобильном приложение можно

посмотреть дни и часы, когда человек принял или не принял тот или иной препарат.

- Гибкая настройка. Таблетницу можно легко и просто настроить с помощью

приложения, в котором можно указать количество препаратов, дни и часы их

принятия, наименование препаратов. В дальнейшем эти данные нужны будут для

ведения статистики.

- Групповое использование. Систему СоТа могут использовать одновременно

несколько человек. Для этого нужно просто перейти в приложении в групповой

режим и привязать к пользователям препараты, которые они должны принимать.

Итоги и результаты

На данный момент готова пробная комплектация таблетницы и реализован

базовый функционал с несколькими дополнительными функциями. Достаточно сложной

задачей было уместить такое большое количество электроники и прочих компонентов в

корпус таблетницы. Само решение показало себя достаточно эффективным, что делает

умную таблетницу удобной для переноски в рюкзаках, сумках и достаточно больших

карманах. Сам корпус имеет размеры около 15 сантиметров в диаметре и 2 сантиметров в

высоту. На данный момент в качестве web-сервиса выступает ТГ бот. В дальнейшей его

планируется заменить на приложение. Также дальнейшие перспективы развития проекта

подразумевают переход от платы ЛУТом на высококачественную плату, изготовленную

на производстве, внедрение ИИ, связи с другими устройствами и голосовой поддержки,

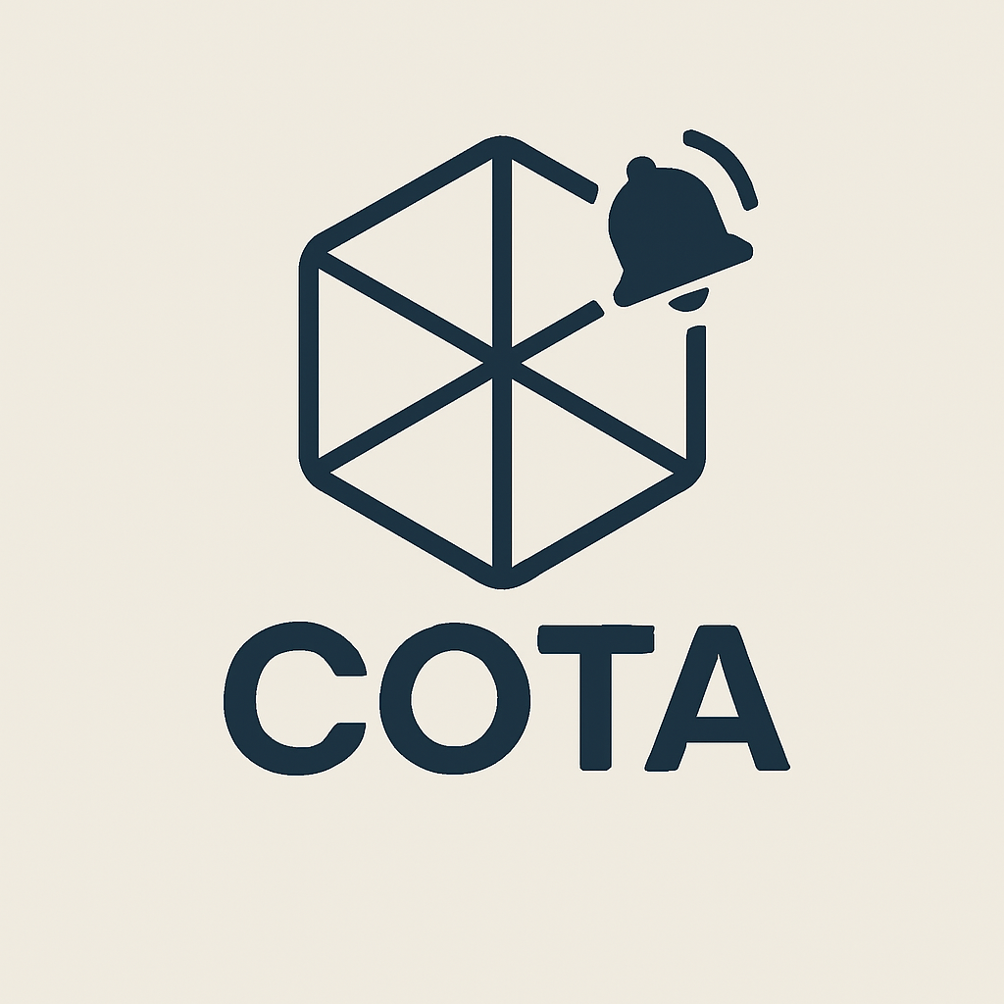
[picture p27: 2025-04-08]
media/SOTA_log.png

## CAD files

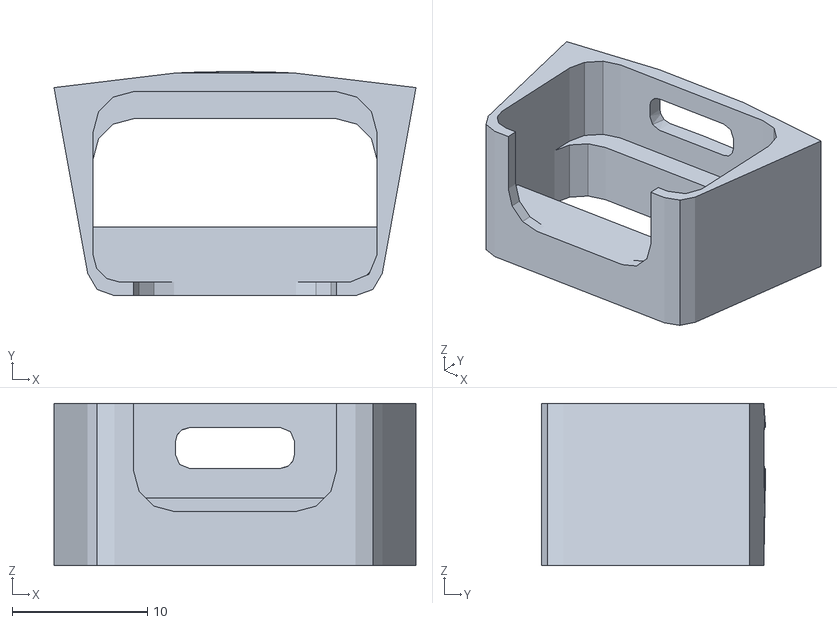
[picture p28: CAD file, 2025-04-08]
hardware/3d_models/3d_printing/STA_ChargingBox.stl
26.8 x 16.6 x 12.0

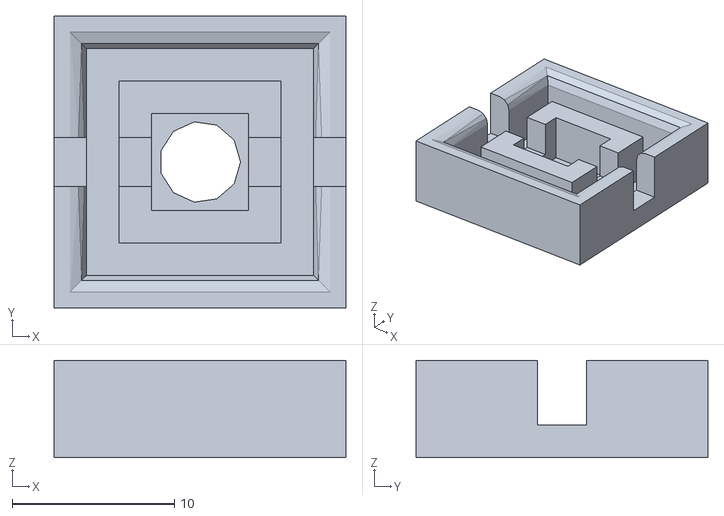
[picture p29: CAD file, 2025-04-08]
hardware/3d_models/3d_printing/STA_ButtonTiles.stl
18.0 x 18.0 x 6.00

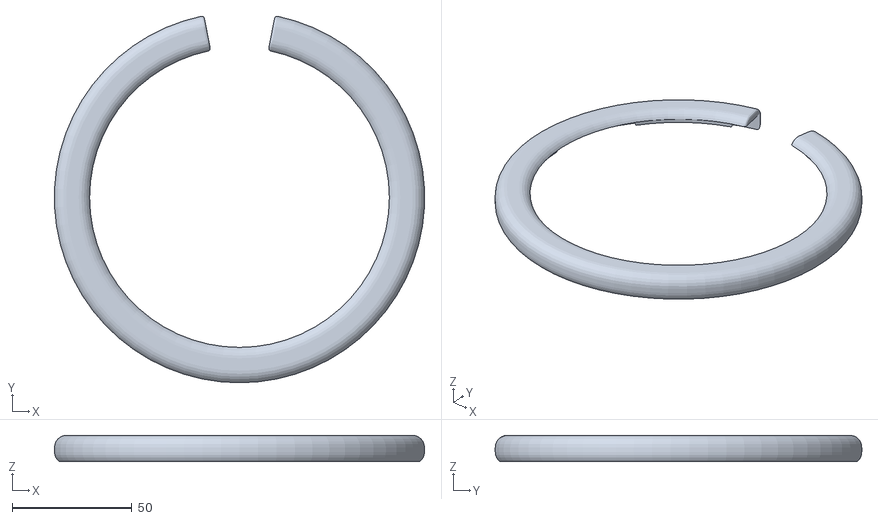
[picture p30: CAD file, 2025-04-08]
hardware/3d_models/3d_printing/STA_Skirt.stl
154.3 x 152.9 x 11.0

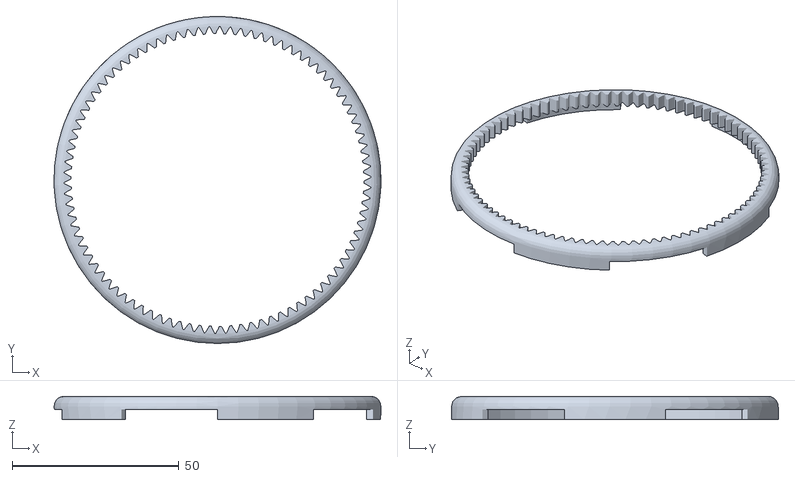
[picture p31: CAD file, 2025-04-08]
hardware/3d_models/3d_printing/STA_GearSkirt.stl
97.9 x 98.0 x 7.00

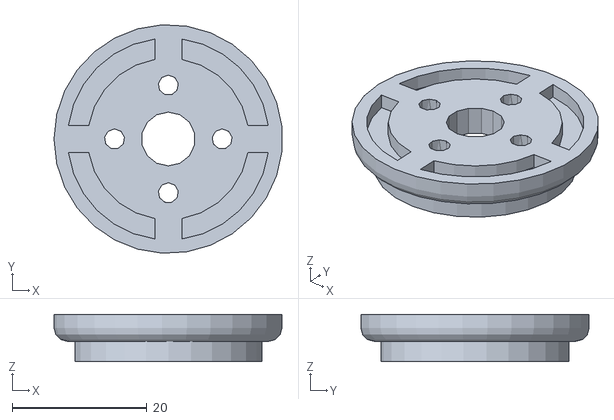
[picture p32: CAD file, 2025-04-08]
hardware/3d_models/3d_printing/STA_LowerPinSupport.stl
33.9 x 34.0 x 7.00

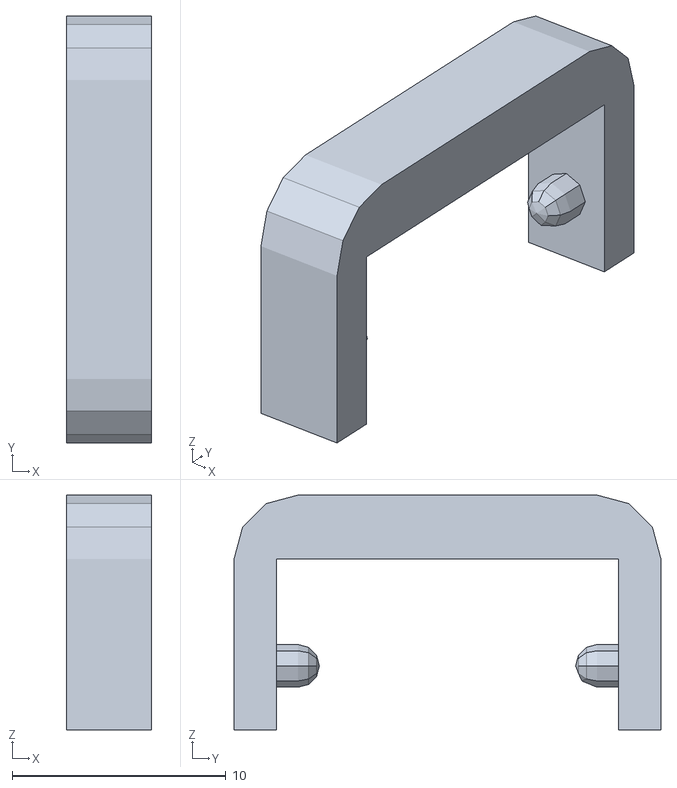
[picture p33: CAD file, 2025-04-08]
hardware/3d_models/3d_printing/STA_Bracket.stl
4.00 x 20.0 x 11.0

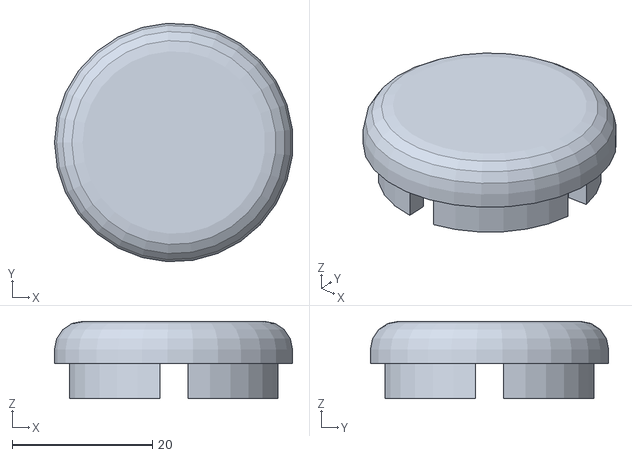
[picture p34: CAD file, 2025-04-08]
hardware/3d_models/3d_printing/STA_UpperPinSupport.stl
33.9 x 34.0 x 11.0

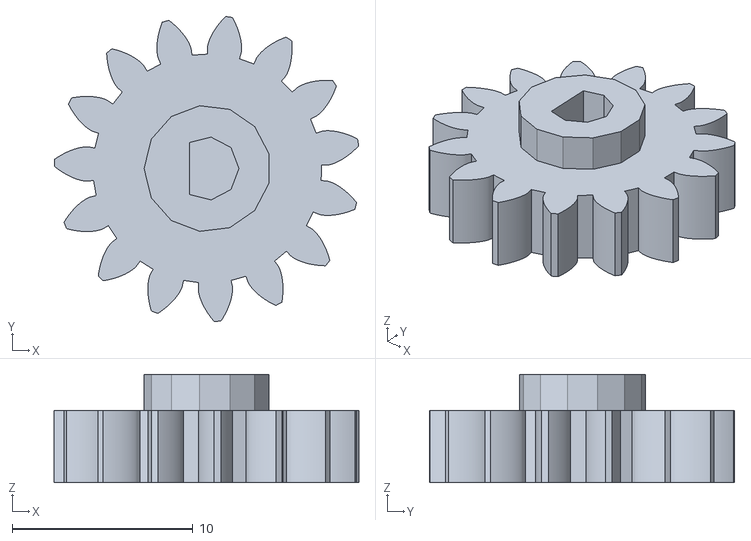
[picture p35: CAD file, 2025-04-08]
hardware/3d_models/3d_printing/STA_GearSmall.stl
16.8 x 16.9 x 6.00

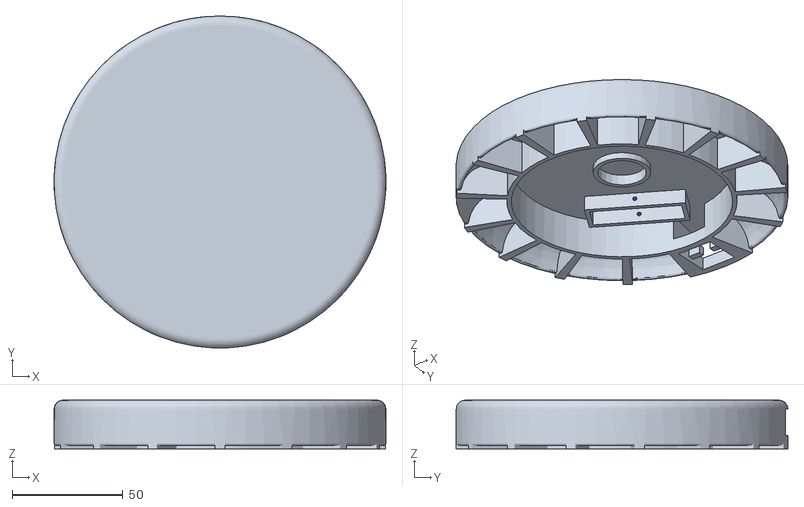
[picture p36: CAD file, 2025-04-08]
hardware/3d_models/3d_printing/STA_Cells.stl
149.9 x 150.0 x 22.0

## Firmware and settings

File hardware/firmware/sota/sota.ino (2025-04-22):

#include <WiFiManager.h>
#include <WiFiClientSecure.h>
#include <PubSubClient.h>
#include <GyverOLED.h>
#include <ArduinoJson.h>
#include <time.h>

// MQTT
const char* mqtt_server = "cffc3c4dda0a4f0f88d3177e3cbb7234.s1.eu.hivemq.cloud";
const int mqtt_port = 8883;
const char* mqtt_user = "Ottobiss";
const char* mqtt_pass = "#Wag#Gloom123";
const char* topic_cmd = "devices/esp32_001/command";
const char* topic_ack = "devices/esp32_001/ack";

WiFiClientSecure wifiClient;
PubSubClient client(wifiClient);
GyverOLED<SSD1306_128x64, OLED_BUFFER> oled;

// Мотор
#define ENC_A 34
#define ENC_B 35
#define MOTOR_IN1 26
#define MOTOR_IN2 27
volatile long encTicks = 0;
int currentCell = 0;
const int ticksPerCell = 332;
const int totalCells = 15;

void IRAM_ATTR onEnc() {
  if (digitalRead(ENC_B)) encTicks++;
  else encTicks--;
}

void initMotor() {
  pinMode(ENC_A, INPUT_PULLUP);
  pinMode(ENC_B, INPUT_PULLUP);
  pinMode(MOTOR_IN1, OUTPUT);
  pinMode(MOTOR_IN2, OUTPUT);
  attachInterrupt(digitalPinToInterrupt(ENC_A), onEnc, RISING);
}

void rotateTo(int target) {
  int fwd = (target - currentCell + totalCells) % totalCells;
  int bwd = (currentCell - target + totalCells) % totalCells;
  bool cw = fwd <= bwd;
  int steps = (cw ? fwd : bwd) * ticksPerCell;

  digitalWrite(MOTOR_IN1, cw ? LOW : HIGH);
  digitalWrite(MOTOR_IN2, cw ? HIGH : LOW);
  encTicks = 0;
  while (abs(encTicks) < steps) delay(1);
  digitalWrite(MOTOR_IN1, LOW);
  digitalWrite(MOTOR_IN2, LOW);
  currentCell = target;
}

// OLED
void showLogo() {
  oled.clear();
  oled.setScale(2);
  oled.setCursor(15, 1);
  oled.print("SOTA");
  oled.setScale(1);
  oled.setCursor(10, 4);
  oled.print("Smart таблетница");
  oled.update();
  delay(2500);
}

void showOLED(const String& l1, const String& l2 = "", const String& l3 = "") {
  oled.clear();
  oled.setScale(1);
  oled.setCursor(0, 0); oled.print(l1);
  oled.setCursor(0, 2); oled.print(l2);
  oled.setCursor(0, 4); oled.print(l3);
  oled.update();
}

void showDose(const String& name, int cell, int dose) {
  oled.clear();
  oled.setScale(2);
  oled.setCursor(0, 0); oled.print(">> "); oled.print(name);

  oled.setScale(1);
  oled.setCursor(0, 4); oled.print("Ячейка: "); oled.print(cell);
  oled.setCursor(0, 6); oled.print("Доза: ");
  for (int i = 0; i < dose; i++) oled.print("+");

  oled.update();
  delay(10000);  // держим экран 10 секунд
}

void showWaiting() {
  oled.clear();
  oled.setCursor(0, 2);
  oled.setScale(2);
  oled.print("Ожидание");
  const char* dots[] = {".", "..", "..."};
  for (int i = 0; i < 6; i++) {
    oled.setCursor(0, 6);
    oled.setScale(1);
    oled.print(dots[i % 3]);
    oled.update();
    delay(400);
  }
}

void showRotating(const String& name) {
  const char* spin[] = {"/", "-", "\\", "|"};
  for (int i = 0; i < 8; i++) {
    oled.clear();
    oled.setCursor(0, 0); oled.print("Готовим:");
    oled.setCursor(0, 2); oled.print(name);
    oled.setCursor(0, 4); oled.print("Вращение ");
    oled.print(spin[i % 4]);
    oled.update();
    delay(120);
  }
}

void sendAck(int cell, const String& name) {
  StaticJsonDocument<256> ack;
  ack["status"] = "ok";
  ack["cell"] = cell;
  ack["name"] = name;
  char buf[256];
  serializeJson(ack, buf);
  client.publish(topic_ack, buf);
}

void callback(char* topic, byte* payload, unsigned int length) {
  payload[length] = '\0';
  StaticJsonDocument<1024> doc;
  if (deserializeJson(doc, payload)) return;
  if (doc["action"] != "rotate") return;

  JsonArray cmds = doc["commands"];
  for (JsonObject cmd : cmds) {
    int cell = cmd["cell"];
    int dose = cmd["dosage"];
    String name = cmd["name"].as<String>();

    showRotating(name);
    rotateTo(cell);
    showDose(name, cell, dose);
    sendAck(cell, name);
  }

  rotateTo(0);
  showWaiting();
}

void setupWiFi() {
  WiFiManager wm;
  showOLED("Подключитесь к", "SOTA", "и настройте сеть");
  if (!wm.autoConnect("SOTA")) ESP.restart();
  showOLED("✅ Подключено к", WiFi.SSID());
}

void setupMQTT() {
  configTime(0, 0, "pool.ntp.org", "time.nist.gov");
  wifiClient.setInsecure();
  client.setServer(mqtt_server, mqtt_port);
  client.setCallback(callback);
}

void reconnectMQTT() {
  while (!client.connected()) {
    client.connect("esp32_tablet", mqtt_user, mqtt_pass);
    delay(1000);
  }
  client.subscribe(topic_cmd);
}

void setup() {
  Serial.begin(115200);
  oled.init();
  initMotor();
  showLogo();
  setupWiFi();
  setupMQTT();
  showWaiting();
}

void loop() {
  if (!client.connected()) reconnectMQTT();
  client.loop();
}

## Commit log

2025-04-08 hardware directory create
    [STA_Bracket.stl, STA_ButtonTiles.stl, STA_Cells.stl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]
2025-04-08 Wiring diagram scheme adding
2025-04-22 Python script and ESP32 script adding
